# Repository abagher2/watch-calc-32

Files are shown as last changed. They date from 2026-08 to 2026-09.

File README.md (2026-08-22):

# StackCalc32 ⌚️🖩

StackCalc32 is a rebellion against slow, clunky school calculators. It completely ditches the equals sign in favor of "Stack Math" (Reverse Polish Notation)—the fastest, most efficient mental hack for solving complex math. Designed to be a world-class, rigorous tool for students, it is available as a suite of Apple ecosystem apps and as a fully open-source physical hardware device.

This monorepo contains the entire project, spanning iOS, watchOS, embedded firmware, and physical hardware designs.

## 🌟 Features

- **True Stack Math Engine**: A robust Reverse Polish Notation core (`RPNCore`) designed for precision, speed, and mathematical rigor without the mess of parentheses.
- **Cross-Platform Software**:
  - **Apple Watch App (`StackCalc32`)**: A full-featured calculator on your wrist, complete with equation plotting, statistical analysis, and complex math functions.
  - **iOS/iPadOS App (`StackCalc32-iOS`)**: A companion app featuring an immersive, haptic-enabled numpad (`HapticNumpadView`) that feels incredibly tactile—like a premium gaming device.
- **Physical Hardware**: Fully open-source 3D models and PCB designs for building your own physical StackCalc32 device. Designed to be ultra-affordable ($10-$15 retail target).
- **Embedded Firmware**: Microcontroller code powering the physical calculator.

## 🚀 The Unfair Advantage

StackCalc32 introduces several modern capabilities designed to give you a massive edge in today's high-speed engineering and math workflows:

- **RPN Equation Editor**: An intuitive editor that feels like programming, but is optimized for quick equation entry and evaluation without the overhead of full program management.
- **Equation Plotting**: Visually plot your equations directly on the screen to analyze functions, roots, and behaviors.
- **Built-in Constants**: A comprehensive library of built-in scientific constants for quick access during calculations.
- **Registers Display List**: Easily view and manage the contents of all your memory registers in a dedicated list view, rather than blindly recalling them one by one.
- **Advanced Division Operations**: Native support for division with remainders and modulus operations.
- **LFU (Least Frequently Used) Keys**: Dynamic keys that adapt to your usage, keeping the interface uncluttered while ensuring you always have access to the functions you need.

## ⌨️ Unique StackCalc32 Capabilities & Keystrokes

While the basic math and variable storage functions mirror the classic HP-32SII, StackCalc32 introduces powerful new capabilities. Here is how to use the features unique to our calculator:

### 1. RPN Equation Editor (Like Programming)
*Unlike the algebraic equation entry on the HP-32SII, StackCalc32 equations are entered as raw RPN sequences—providing the power of programming without the overhead of full program memory management.*
*Note on display formatting: The display shows the step number followed by the instruction (e.g., `3 RCL X` means step 3 is RCL X).*

*Example: Enter the equation `Y = 56 × X + 3`*

| Keystrokes | Display | Explanation |
| :--- | :--- | :--- |
| `[Blue Shift]` `[EQN]` | `EQN List` | Opens the Equation Editor list. |
| `[+]` *(New Eq)* | `LBL _` | Starts a new equation and prompts for a label. |
| `[A]` | `00 LBL A` | Assigns the equation to label A. |
| `5` `6` `[ENTER]` | `1 56` | Enters 56 into the sequence (step 1). |
| `[RCL]` `[X]` | `2 RCL X` | Recalls variable X (step 2). |
| `[×]` | `3 ×` | Multiplies 56 by X (step 3). |
| `3` `[+]` | `5 +` | Adds 3 to complete the RPN equation (steps 4 and 5). |

### 2. Equation Plotting
*Plot the equation you just entered to analyze its behavior visually.*

| Keystrokes | Display | Explanation |
| :--- | :--- | :--- |
| `[Blue Shift]` `[EQN]` | `A 56 RCL X × 3 +` | Select the equation from the list (it displays the full sequence). |
| `[Yellow Shift]` `[PLOT]` | `Plot Y(X)?` | Prompts for the independent variable to sweep (default X). |
| `[ENTER]` | `Plotting...` | Renders a high-res, pan/zoomable plot of the equation. |

### 3. Graphical Registers & Constants Lists
*Say goodbye to blindly guessing what is stored in your variables.*

| Keystrokes | Display | Explanation |
| :--- | :--- | :--- |
| `[Blue Shift]` `[REGS]` | `Registers...` | Opens a scrollable graphical list of all stored memory registers (A-Z). |
| `[Blue Shift]` `[CONST]` | `Constants...` | Opens the built-in scientific constants library for quick insertion. |

### 4. Advanced Division & Modulus
*Calculate integer division and remainders natively.*

| Keystrokes | Display | Explanation |
| :--- | :--- | :--- |
| `1` `7` `[ENTER]` `5` | `5.0000` | Pushes 17 and 5 to the stack. |
| `[Yellow Shift]` `[÷]` | `3.0000` | Integer division (`17 // 5`). |
| `[Yellow Shift]` `[MOD]` | `2.0000` | Returns the remainder (`17 % 5`). |

### 5. Dynamic LFU Keys
StackCalc32 features **Least Frequently Used (LFU)** adaptive keypads. As you use specific functions or variables, the interface gracefully adapts to surface your most-used keys, preventing you from having to dig through shift menus for your favorite operations.

## 📂 Repository Structure

To maintain a clean and organized monorepo ready for public open-source distribution, this repository strictly adheres to the following structure:

- `StackCalc32/` - The watchOS application target.
- `StackCalc32-iOS/` - The iOS/iPadOS application target (Container App).
- `RPNCore/` - The shared, core RPN mathematical engine.
- `Shared/` - Shared SwiftUI views, themes, and logic used across both Apple platforms.
- `Hardware/` - Physical calculator design files, including KiCAD schematics (`.kicad_sch`), PCB layouts (`.kicad_pcb`), OpenSCAD 3D models, and gerber files.
- `Firmware/` - Embedded Swift / C code for the physical microcontroller.
- `fastlane/` - Automated App Store screenshots, metadata, and submission scripts.
- `scratch/` - *(Git-ignored)* Directory for temporary scripts, parsed logs, exploratory testing, and raw extractions.

## 🛠️ Development & Building

### iOS & watchOS Apps

This project uses [XcodeGen](https://github.com/yonaskolb/XcodeGen) to manage the Xcode project configuration, eliminating `.pbxproj` merge conflicts.

1. Ensure XcodeGen is installed (e.g., via Homebrew): 
   ```bash
   brew install xcodegen
   ```
2. Generate the Xcode project:
   ```bash
   xcodegen generate
   ```
3. Open `StackCalc32.xcodeproj` in Xcode and select the target (`StackCalc32Container` for iOS/iPad or `StackCalc32` for Apple Watch) to build and run.

### Hardware & Firmware

- **3D Models**: Modify the `.scad` files in `Hardware/` and use the provided `generate_scad.py` script to compile the final `.stl` files for 3D printing. *(Note: To keep the repository light, `.stl` files are explicitly git-ignored).*
- **Firmware**: Built using the Apple Swift Embedded toolchain or Raspberry Pi Pico SDK. See the `Firmware/` directory for specific hardware bring-up and build instructions.

## 📄 License & Privacy

- **License**: Please refer to the [LICENSE](LICENSE) file for open-source licensing details.
- **Privacy Policy**: See the [Privacy Policy](PRIVACY_POLICY.md) for information regarding data collection (StackCalc32 does not collect or store user data).

---
*Built for the next generation of engineers who appreciate the elegance of RPN.*

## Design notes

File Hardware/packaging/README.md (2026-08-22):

# StackCalc32 Packaging & Dielines

This directory contains the physical packaging designs, dielines, and concepts for StackCalc32. Our packaging strategy employs a dual-box system tailored for both Direct-to-Consumer (D2C) e-commerce and traditional retail channels.

## 1. D2C Mailer Box
For our Amazon and D2C online sales, we use a minimalist, eco-friendly corrugated mailer.

- **Objective:** Survive shipping, reduce environmental impact, and provide a rebellious unboxing experience.
- **Design:** Kraft brown cardboard with bold, edgy black typography.
- **Slogan:** "Ditch the Equals Sign."
- **Internal:** Custom high-density foam insert cut to the exact chassis dimensions.
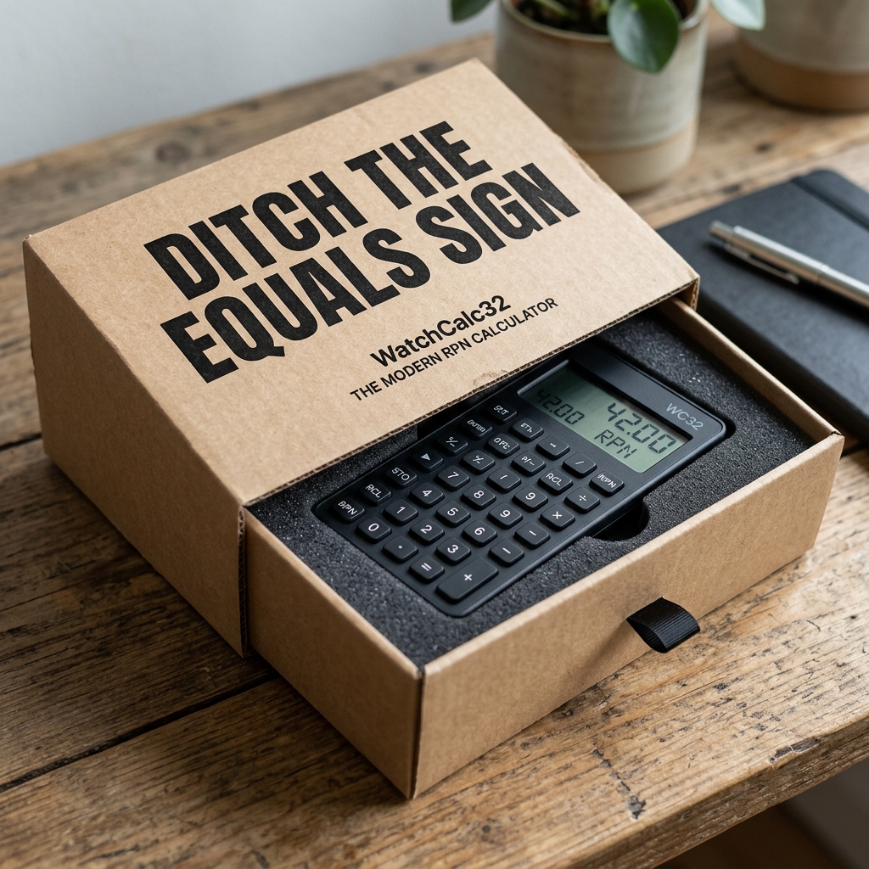
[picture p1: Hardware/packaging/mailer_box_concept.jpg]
D2C Mailer Concept
- **Concept Image:** 

## 2. Retail Display Box
For physical store shelves (e.g., Walmart, office supply stores), we use a high-gloss tuck-end box designed to pop off the shelf and appeal to students/teenagers.

- **Objective:** Maximum shelf appeal, highlight the modern UI, and clearly differentiate from boring legacy calculators.
- **Design:** Dark mode aesthetics with vibrant neon/tech accents. Features high-res screenshots of the equation editor and plot view.
- **Interactive:** Large QR code on the front linking directly to the companion app/tutorials.
- **Slogan:** "Ditch the Equals Sign."
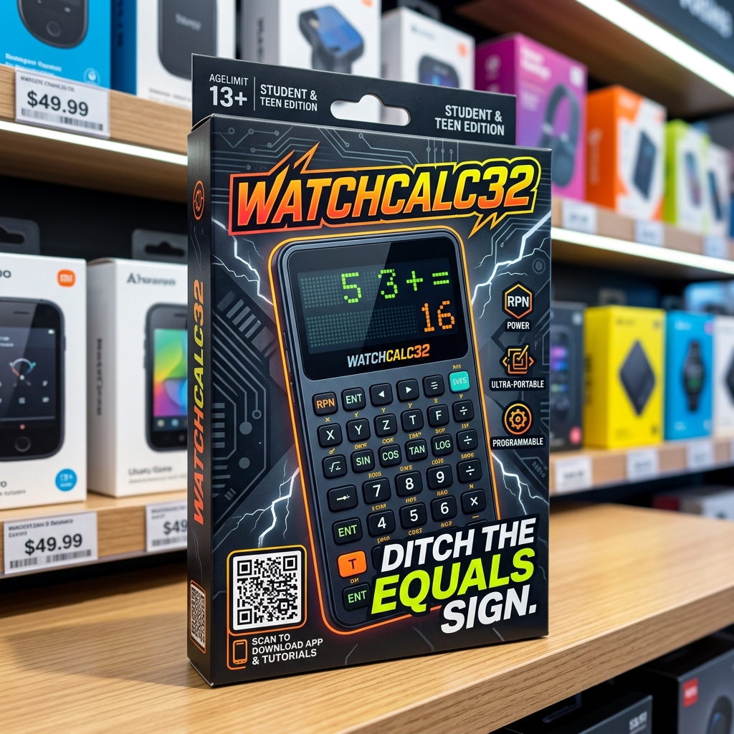
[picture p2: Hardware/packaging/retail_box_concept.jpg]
Retail Box Concept
- **Concept Image:** 

## 3. Production Specs & Cost of Goods Sold (COGS)
To achieve our target retail price of **$10–$15**, the total manufacturing cost (COGS) must remain strictly under **$4.00 per unit** to allow for 3PL, freight, and retail margins.

### BOM Target Breakdown ($3.50 total):
- **MCU:** CH32V or RP2040 (~$0.15 - $0.70)
- **Display:** 1.8" Monochrome Graphic LCD SPI (~$0.85)
- **Keypad:** Silicone dome membrane keypad with printed plastic caps (~$0.40)
- **Chassis:** Injection-molded ABS plastic (~$0.50)
- **Packaging:** 300gsm tuck-end box with molded pulp tray (more sustainable and cheaper than EVA foam) (~$0.30)
- **PCBA & Assembly Labor:** (~$0.60)

*Note: We cannot use premium mechanical keyboard switches or full-color OLED screens without breaking this strict budget constraint.*

## Next Steps for Production
1. **Dieline Generation:** Once the final chassis dimensions are locked in `Hardware/designs/chassis.scad`, we will generate 2D `.dxf` / `.ai` dielines for the box fold patterns based on the 300gsm tuck-end spec.
2. **Pulp Tray Routing:** Generate step files for the internal molded pulp tray so the manufacturer can press the exact cutout for the calculator and charging cable.
3. **Artwork Layout:** Apply the high-res marketing renders to the flattened dielines for printing.

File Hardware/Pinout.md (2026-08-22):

# RP2040-Zero PCB Pinout & Wiring Plan

To test the connections on your custom PCB, map out exactly which GPIO pins connect to which components.

## 1. Pin Assignments (Modern Layout)

This pinout maps to the 43-key Modern matrix (8 rows x 6 columns) as generated by our KiCad config.

### OLED Display (I2C)
*   **VCC** -> 3.3V (Out)
*   **GND** -> GND
*   **SDA** -> GP0
*   **SCL** -> GP1

### Keyboard Matrix (6 Columns x 8 Rows)
The RP2040 will pull the 6 columns low sequentially and read the 8 rows to scan all 43 physical keys.

**Column Pins (Outputs):**
*   **Col 1** -> GP10
*   **Col 2** -> GP11
*   **Col 3** -> GP12
*   **Col 4** -> GP13
*   **Col 5** -> GP14
*   **Col 6** -> GP15

**Row Pins (Inputs with Pull-ups):**
*   **Row 1 (Top)** -> GP5
*   **Row 2** -> GP6
*   **Row 3** -> GP7
*   **Row 4** -> GP8
*   **Row 5** -> GP26
*   **Row 6** -> GP27
*   **Row 7** -> GP28
*   **Row 8 (Bottom)** -> GP29

---

## 2. Testing the Board
Once your PCB is manufactured and soldered, plug the RP2040-Zero into your computer via USB-C. 
Install **MicroPython** on it, and run the `board_test.py` script provided in this folder to verify all 43 keys register correctly.

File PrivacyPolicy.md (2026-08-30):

# Privacy Policy

**Effective Date:** 2024-05-15

StackCalc32 ("the App") is designed with your privacy in mind. This policy explains our data practices.

## 1. Data Collection
StackCalc32 operates entirely locally on your device (iPhone, iPad, or Apple Watch). 
We do not collect, transmit, store, or share any personal information, usage data, or calculations.

All calculator states, memory registers, user equations, and settings are stored locally on your device using standard Apple frameworks (such as UserDefaults) and are never shared.

### Third-Party Services
The App does not integrate with any third-party analytics or advertising services. 

### Contact Us
If you have any questions regarding this privacy policy or our data practices, please open an issue on our GitHub repository.

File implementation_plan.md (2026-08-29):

# Fix Spring Attachments, ENTER Shaft, and Key Labels

This plan addresses all issues found in the recent slicer review of the print-in-place calculator keypad.

## Proposed Changes

### 1. Fix Spiral Spring Attachments
- **Issue:** The spiral springs currently stop at `r=4.0`, while the button cavity is `w+btn_gap` (~9.3mm). This leaves the ends of the springs floating in mid-air, requiring supports.
- **Fix:** Modify `button_solid` to calculate the exact distance to the cavity wall (`w/2 + btn_gap/2`). Extend the `spiral_arm` radius to completely bridge the gap.
- **Result:** The spiral arms will fuse perfectly to the faceplate cavity walls during slicing, anchoring the buttons without any supports.

### 2. Fix ENTER Button Shaft
- **Issue:** The ENTER button was generated with two inner shafts, which does not align with the single tactile switch on the PCB.
- **Fix:** Remove the `if (w > 15)` double-shaft logic in `generate_scad.py`. All buttons (including ENTER) will use a single, centrally-aligned inner shaft and spring mechanism.

### 3. Extract and Apply All iOS App Labels
- **Issue:** Side labels were only applied to a few keys using dummy data.
- **Fix:** Parse `HP32KeyMap.swift` to extract the `yellowLabel`, `blueLabel`, and `alphaLabel` for every single key on the grid.
- **Mapping:** 
  - `yellowLabel` -> Left Skirt (`label_left`)
  - `blueLabel` -> Right Skirt (`label_right`)
  - `alphaLabel` -> Front Skirt (`label_alpha`)

### 4. Rotate and Deepen Side Labels
- **Issue:** Side labels are oriented vertically, and the emboss depth is too shallow.
- **Fix:** Update the label `rotate()` transformations in `generate_scad.py` so they read horizontally (left-to-right) along the Y-axis. Increase the subtraction depth to `0.8mm` to ensure they slice clearly.

## User Review Required
Please approve this plan so I can proceed with patching the Python generator and extracting the exact labels from your iOS source code!

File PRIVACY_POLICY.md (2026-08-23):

# Privacy Policy

**Effective Date:** August 19, 2026

StackCalc32 ("the App") is an RPN scientific calculator application provided for iOS, iPadOS, and watchOS devices.

## Data Collection and Use
We do not collect, store, transmit, or share any personal information, usage data, or analytics from your device. All calculations and operations performed within the App occur locally on your device.

## Third-Party Services
The App does not use any third-party services that may collect information used to identify you.

## Changes to This Privacy Policy
We may update our Privacy Policy from time to time. Thus, you are advised to review this page periodically for any changes. We will notify you of any changes by posting the new Privacy Policy on this page. These changes are effective immediately after they are posted on this page.

## Contact Us
If you have any questions or suggestions about our Privacy Policy, do not hesitate to contact us by creating an issue in this repository.

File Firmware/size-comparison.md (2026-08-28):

## SwissMicros DM32 (Modern Clone):
Width: 77.0 mm
Height: 144.0 mm
Depth: 12.0 mm

## Original HP-32SII (Authentic Vintage):
Width: 85.0 mm
Height: 148.0 mm
Depth: 15.0 mm

## Our StackCalc 32 (Bare Chassis):
Width: 76.0 mm
Height: 148.0 mm
Depth: ~15.0 mm

## Our StackCalc 32 (with TPU Cover):
Width: 79.2 mm
Height: 151.2 mm
Depth: ~16.6 mm

**StackCalc 32 Screen**
https://www.buydisplay.com/2-5-inch-132x65-arduino-lcd-display-module-serial-spi-black-on-white

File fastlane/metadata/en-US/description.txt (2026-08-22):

Ditch the equals sign. WatchCalc 32 is a rebellion against slow, boring, clunky school calculators. 

Tired of getting lost in a mess of parentheses on your math homework? WatchCalc 32 uses "Stack Math" (Reverse Polish Notation)—the fastest, most efficient mental hack for solving complex math. It's like a cheat code for your exams. Built as a companion app to the physical WatchCalc 32 hardware, this app gives you pure mathematical power across your iPhone, iPad, and Apple Watch.

### Key Features

• Stack Math (RPN) Logic: Experience raw speed. Type your numbers, stack them up, and execute. No equals sign required.
• Purpose-Built for Exams: Intentionally non-programmable so you can actually use it in class without getting flagged by your teacher.
• Powerful Engine: Tackle advanced operations including exact fractions, complex numbers, statistics, trigonometry, and base conversions.
• Equation Plotting: Evaluate and visualize complex equations instantly with dynamic, full-screen interactive graphs. 
• True Cross-Platform: Fully optimized. Hyper-efficient layout on Apple Watch, one-handed portrait mode on iPhone, and an expansive landscape mode on iPad.
• Edgy Aesthetics: Dark mode, neon accents, and tactile haptic feedback that makes it feel like you're holding a premium gaming device, not a 1990s school supply.

Download the ultimate mathematical cheat code and never press equals again.

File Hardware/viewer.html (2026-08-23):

# WatchCalc 32 Assembly

Loading models...

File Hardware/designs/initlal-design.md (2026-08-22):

StackCalc32: Apple Watch RPN CalculatorVersion: 1.0 (Architecture & UI Specification)Target Platform: watchOS 10+ (Apple Watch Series 7, 8, 9, Ultra)Frameworks: SwiftUI, Charts, Swift 5.9, C/C++Core Engine: Advanced (WP43S) or Free42 C/C++ Core1. Executive SummaryStackCalc32 brings the mathematical rigor of the HP-32SII and Advanced to the Apple Watch. It solves the "micro-button" problem of watch calculators by utilizing a Continuous Vertical Ribbon (a scrolling UI), Screen-Wide Gestures (eliminating modifier keys), and Native Apple Input (for variables and equations). The aesthetic mimics the molded plastic of the Pioneer chassis (e.g., SwissMicros Modern).2. System ArchitectureThe application strictly decouples the UI from the math engine using a Local Swift Package Manager (SPM) architecture.2.1 Workspace StructureWatchCalcWorkspace/
├── StackCalc32_AppTarget/
│   ├── UI Components (SwiftUI)
│   └── App.swift
└── RPNCore (Local Swift Package)/
    ├── Package.swift
    ├── Sources/
    │   ├── CEngine/
    │   │   ├── include/CEngine.h (C Public API)
    │   │   └── core_logic.c (Advanced/Free42 source)
    │   └── RPNCore/
    │       └── CalculatorEngine.swift (Swift Wrapper)
2.2 The State Machine (CalculatorEngine.swift)The Swift layer acts as a bidirectional terminal between SwiftUI and the C core.import Foundation
import CEngine
import SwiftUI

@Observable
public class CalculatorEngine {
    // Standard Display State
    public var displayX: String = "0.0000"
    public var promptString: String? = nil // Handles display takeovers e.g. "STO _"
    
    // Shift State: 0=None, 1=Yellow(f), 2=Blue(g)
    public var shiftState: Int = 0 
    
    // 8-Level Stack Array (For Overlay)
    public var stack: [String] = Array(repeating: "0.0000", count: 8)
    
    // Mode Tracking
    public var isEquationMode: Bool = false
    public var equationString: String = ""
    
    public init() {
        c47_init()
        updateState()
    }
    
    public func execute(command: String) {
        // Map string identifier to C command and execute
        c47_execute_cmd(mapToID(command))
        updateState()
    }
    
    public func setShift(_ state: Int) {
        self.shiftState = state
        WKInterfaceDevice.current().play(.click)
    }
    
    private func updateState() {
        // Pseudo-logic to query C Engine
        if c47_is_waiting_for_input() {
            self.promptString = String(cString: c47_get_prompt())
        } else {
            self.promptString = nil
            self.displayX = String(cString: c47_get_display_x())
        }
        
        // Update deep stack
        for i in 0..<8 {
            if let val = c47_get_stack_level(Int32(i)) {
                self.stack[i] = String(cString: val)
            }
        }
    }
}
3. The Universal Gesture MatrixButtons on the screen act as static spatial targets. All modifiers and actions are routed through watchOS screen gestures.GestureActionEngine CommandHaptic FeedbackSwipe UpPush to StackENTER.successSwipe DownClear X / Cancel MenuCLx / EXIT.retrySwipe LeftReveal Math Operators PadN/A (UI state).directionUpSwipe RightReveal ASSIGN (LFU) MenuN/A (UI state).directionDownSwipe Display LeftToggle Yellow Shift (f)N/A (UI state).clickSwipe Display RightToggle Blue Shift (g)N/A (UI state).click (Double)Tap DisplayOpen 8-Level Stack OverlayN/A (UI state).clickDigital CrownScroll Keyboard RibbonN/A (UI state)Native Detents4. Visual Language & AestheticsThe UI simulates molded plastic with inner highlights and drop shadows, avoiding bitmaps for Retina sharpness.4.1 Color Paletteextension Color {
    static let dmChassis = Color(white: 0.1) // Background
    static let dmDigitKey = Color(white: 0.85) // 0-9
    static let dmFunctionKey = Color(white: 0.25) // Math functions
    static let dmYellowShift = Color(red: 1.0, green: 0.8, blue: 0.1)
    static let dmBlueShift = Color(red: 0.2, green: 0.8, blue: 1.0)
}
4.2 The Pioneer Button Stylestruct PioneerButtonStyle: ButtonStyle {
    var isDigit: Bool
    
    func makeBody(configuration: Configuration) -> some View {
        configuration.label
            .background(
                RoundedRectangle(cornerRadius: 6, style: .continuous)
                    .fill(isDigit ? Color.dmDigitKey : Color.dmFunctionKey)
            )
            .overlay( // 3D Top Bevel
                RoundedRectangle(cornerRadius: 6, style: .continuous)
                    .stroke(LinearGradient(gradient: Gradient(colors: [.white.opacity(0.4), .clear]), startPoint: .topLeading, endPoint: .bottomTrailing), lineWidth: 1.5)
            )
            .shadow(color: .black.opacity(configuration.isPressed ? 0.0 : 0.6), radius: configuration.isPressed ? 0 : 2, y: configuration.isPressed ? 0 : 2)
            .scaleEffect(configuration.isPressed ? 0.92 : 1.0)
    }
}
5. Viewport / Layout SpecificationsThe UI exists in a single vertical ScrollView. As the user scrolls up via the Crown, the grid safely expands from 3 columns to 4.5.1 The LCD Display (Pinned Header)A static, single-line display pinned to the top of the screen. Utilizes SF Mono Bold. If promptString is active, it takes over the X-register view.5.2 The Bottom Viewport (Data Entry - 3x4 Grid)Scroll Offset = 0.7, 8, 94, 5, 61, 2, 30, ., +/-5.3 The Upper Matrix (Scientific - 4x5 Grid)Scroll Offset < 0. Located directly above the Numpad.STO, RCL, x><y, R↓1/x, √x, LN, LOGSIN, COS, TAN, R/SFN=, ∫, ABS, INTGLBL, GTO, EQN, SOLVE5.4 The "Hold to Preview" LogicTo prevent accidental shifted clicks, custom gesture logic replaces standard buttons in the Upper Matrix:Touch Down: Shows the key's target function (e.g., "ASIN") on the LCD promptString.Drag Away: Cancels the press and clears the LCD preview.Release inside bounds: Executes the function.6. Advanced Subsystems6.1 Native Alpha Entry (Variables / STO)When the Advanced engine waits for a variable (e.g., STO _), the UI must trigger the native watchOS text entry.engine.promptString updates to "STO _".SwiftUI triggers .sheet(isPresented: $isWaitingForAlpha).User utilizes Apple Scribble or QWERTY keyboard.OnSubmit, Swift sanitizes to a single uppercased String and passes CMD_ALPHA_A to Advanced.6.2 Equation & Solve EngineWhen EQN is active, the single-line LCD swaps to a horizontal ScrollView (Ticker).Users can type equations via the 4x5 ribbon OR tap a keyboard icon to open native watchOS dictation/keyboard.Swift parses Y=3X^2 string into sequential Advanced engine commands.6.3 Plotting / Graphing Engine (Oscilloscope Mode)Integrated via SwiftUI Charts. Triggered from Equation mode.struct FullScreenPlotView: View {
    @StateObject var plotEngine: PlotEngine // Runs loop to evaluate Advanced equation 150 times
    @State private var crownZoom: Double = 10.0
    
    var body: some View {
        Chart(plotEngine.dataPoints) { point in
            LineMark(x: .value("X", point.x), y: .value("Y", point.y))
                .interpolationMethod(.monotone)
                .foregroundStyle(Color.dmBlueShift)
        }
        .chartXScale(domain: -crownZoom...crownZoom)
        .chartYScale(domain: -crownZoom...crownZoom)
        .focusable(true)
        .digitalCrownRotation($crownZoom, from: 1, through: 100, sensitivity: .medium)
    }
}
7. Recommended Development PhasesPhase 1: SPM & Engine. Create local package, wrap Advanced/Free42 C code, build bidirectional @Observable engine class.Phase 2: Skin & Gestures. Build the Modern UI components, the 3x4 Numpad, and wire the Swipe Up/Down/Left gestures.Phase 3: The Ribbon. Implement the ScrollView, the 4x5 upper matrix, and the display header logic (shift states).Phase 4: Integrations. Add the Native watchOS text field handoffs for Alpha entry and the SwiftUI Charts for plotting.

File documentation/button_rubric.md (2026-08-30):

# HP32SII Deviation Rubric

This document tracks **only the ways StackCalc32 intentionally deviates from the original HP32SII**. Any key combination not listed here is expected to behave identically to the HP32SII (or DM32 where noted). Refer to the [HP 32SII Owner's Manual](https://www.hpcalc.org/hp32s/) and [DM32 User Manual](https://technical.swissmicros.com/dm32/) for baseline behavior.

For a full description of how every menu operates across all surfaces, see [menu_operation.md](menu_operation.md).

---

## Base State — Key Remaps & Additions

These keys exist on the physical StackCalc32 hardware but **differ in label or function** from the HP32SII.

| Button / Combo | HP32SII Original | StackCalc32 | Rationale |
|---|---|---|---|
| **BLUE + +/-** | `(` (open parenthesis — for EQN/solver entry) | `\|x\|` (Absolute Value) | Parentheses are less useful in RPN direct mode; ABS is more ergonomic. |
| **BLUE + E** | `)` (close parenthesis — for EQN/solver entry) | `÷R` (Integer Division) | Parentheses serve EQN mode only; `÷R` is more useful as a direct key. |
| **BLUE + <-** | `=` (equals — for EQN/solver entry) | *(no function)* | `=` is not needed in RPN mode; key is left unassigned. |
| **YELLOW + 0** | `INPUT` (program input prompt — recall var and show name+value) | `REGS` (Show Registers) | `INPUT` is programming-only. StackCalc32 repurposes the key for the register viewer. |
| **PLOT** | *(key does not exist on HP32SII)* | Opens Plot Mode | StackCalc32-exclusive key. Not on the HP32SII or DM32. |
| **YELLOW + PLOT** | *(key does not exist)* | `CNST` (Physical Constants Menu) | StackCalc32-exclusive. HP32SII has no built-in constants menu; users stored constants in registers. |

---

## LFU Row (Top 6 Dynamic Softkeys)

The **LFU (Least Frequently Used) row** is a StackCalc32-exclusive feature. The HP32SII has **no dedicated softkey row** — its top row of keys (`√𝑥`, `𝑒ˣ`, `LN`, `𝑦ˣ`, `¹/𝑥`, `Σ+`) are always fixed math function keys, with no dynamic softkey strip at all.

StackCalc32 permanently reserves the top 6 keys as a dynamic, context-aware softkey strip. In menu contexts, this LFU row repurposes identically to how the HP32SII repurposed its numeric top row — except it is reserved for this purpose at all times rather than only during menus.

| Context | HP32SII Original | StackCalc32 Firmware / RetroUI | iOS / watchOS |
|---|---|---|---|
| **Normal State** | Top row = `√𝑥 𝑒ˣ LN 𝑦ˣ ¹/𝑥 Σ+` (always fixed) | Top row shows 6 most recently used functions (LFU algorithm) | N/A — no physical row |
| **Menu Active** | Top numeric row remapped to softkey labels | LFU row remaps to softkeys (e.g., `FIX SCI ENG ALL`) | Native sheet / list replaces entirely |
| **EQN List** | *(no softkeys — navigate with `↓`/`↑` only)* | LFU row shows `EQN_NEW`, `EQN_EDIT` softkeys | Native list with `+` button and swipe-to-delete |

---

## Menu Navigation Model

All menus exist on all three surfaces and produce identical calculator results. The **mechanism** differs by surface. This is not a functional deviation — it is a platform adaptation.

| Surface | How Menus Are Navigated |
|---|---|
| **HP32SII** | Physical softkey row (top numeric keys) remapped to menu labels during menu state. User presses the key physically below the label on the LCD. Multi-page menus use a `▸` page key. |
| **Firmware / RetroUI** | LFU row replaces the softkey row. Same single-press selection. `requiresDigit` menus (FIX, SCI, ENG, SF, CF) wait for a follow-up digit keypress on the same row. |
| **iOS** | Native modal sheet with tappable list items. `requiresDigit` menus present an inline digit picker. Dismisses automatically after selection. |
| **watchOS** | Full-screen SwiftUI list. Tap or Digital Crown to select. Sub-picker for digit-requiring options. |

> [!NOTE]
> See [menu_operation.md](menu_operation.md) for the complete per-menu breakdown of items and behavior on each surface.

The following menus are present on all surfaces with **no functional deviation** from the HP32SII. Only the navigation mechanism differs as described above:

| Menu | Trigger | HP32SII Items | StackCalc32 Additions |
|---|---|---|---|
| **DISP** | `YELLOW + E` | `FIX n`, `SCI n`, `ENG n`, `ALL` | — |
| **MODES** | `YELLOW + +/-` | `DEG`, `RAD`, `GRAD` | — |
| **BASE** | `YELLOW + ×` | `HEX`, `DEC`, `OCT`, `BIN` | — |
| **CLEAR** | `YELLOW + <-` | `CLx`, `CLVARS`, `CLΣ`, `ALL` *(PGM only in PRGM mode)* | `CLEQN`, `CLREGS`, `CLSTK` added as always-visible items |
| **FLAGS** | `BLUE + ×` | `SF n`, `CF n`, `FS? n`, `FC? n` | `4-LVL`, `8-LVL`, `INF` stack-size options |
| **MEM** | `YELLOW + x≷y` | `VARS`, `PRGM`, `REGS` | — |
| **PARTS** | `BLUE + √𝑥` | `IP`, `FP`, `ABS` | `SGN` added |
| **PROB** | `BLUE + 𝑒ˣ` | `Cn,r`, `Pn,r`, `𝑥!`, `RAND` | — |
| **SUMS** | `BLUE + Σ+` | `Σx`, `Σy`, `Σx²`, `Σy²`, `Σxy`, `n` | — |
| **𝑥̄,𝑦̄** | `BLUE + 𝑦ˣ` | `x̄`, `ȳ`, `x̄w` | — |
| **s,σ** | `BLUE + ¹/𝑥` | `sx`, `sy`, `σx`, `σy` | — |
| **L.R.** | `BLUE + LN` | `ŷ`, `x̂`, `r`, `m`, `b` | — |
| **𝑥?𝑦** | `YELLOW + ÷` | `x=y`, `x≠y`, `x>y`, `x<y`, `x≥y`, `x≤y` | — |
| **𝑥?0** | `BLUE + ÷` | `x=0`, `x≠0`, `x>0`, `x<0`, `x≥0`, `x≤0` | — |

---

## Modeless / State-Specific Deviations

### 1. Programming / Equation Mode (EQN Edit)

> [!IMPORTANT]
> This is the **largest intentional deviation** from the HP32SII.

The HP32SII uses **algebraic entry** for equations (e.g., `SIN(X) + 1`). StackCalc32 intentionally deviates: all equation equations use **RPN instruction entry** (appending steps like `SIN`, `1`, `+`). This creates a unified execution model across the physical device, iOS, and watchOS.

| Button / Combo | HP32SII Original | StackCalc32 |
|---|---|---|
| **Base Functions (SIN, COS, etc.)** | Appends algebraic text character(s) to equation | Appends RPN instruction step |
| **Numpad** | Appends digit(s) to algebraic expression | Appends numeric constant as a discrete step |
| **ENTER** | Submits the algebraic equation | Commits the current RPN program to storage |
| **`<-` / C** | Backspaces one character in algebraic string | Deletes the previous RPN instruction step |

---

### 2. Plot Mode — `PLOT` key

The HP32SII has **no Plot Mode**. This entire section is a StackCalc32 extension.

| Button / Combo | HP32SII Original | StackCalc32 |
|---|---|---|
| **PLOT** | *(key does not exist)* | Enters Plot Mode — transitions UI to graph renderer |
| **Numpad 2/4/6/8** | *(N/A)* | Pans graph (Down/Left/Right/Up) |
| **+ / -** | *(N/A)* | Zooms in/out |
| **`<-` / C** | *(N/A)* | Exits plot, returns to normal mode |
| **LFU Keys (Top 6)** | *(N/A)* | Reserved for trace mode (not yet implemented) |

---

### 3. Alpha Mode — Platform Differences Only

The Alpha entry mode (triggered by `STO _`, `RCL _`, `XEQ _`, etc.) behaves identically to the HP32SII on the Firmware/RetroUI surface. The iOS and watchOS surfaces deviate only at the **input mechanism level** — the calculator engine behavior is identical.

| Platform | Alpha Input Method | Deviation from HP32SII? |
|---|---|---|
| **Firmware / RetroUI** | Physical alpha key labels (`A`–`Z` printed on key faces) | **No deviation** |
| **iOS** | Native iOS keyboard sheet | UI-level only — engine accepts same inputs |
| **watchOS** | Full-screen A–Z picker | UI-level only — engine accepts same inputs |

---

### 4. Error Handling and Prompts (Nuanced Deviations)

*   **Error States**: When an operation causes a mathematical exception (e.g., `DIVIDE BY 0`, `INVALID DATA`, `OVERFLOW`, `STAT ERROR`), the engine halts and displays the error message on the LCD.
    *   **Deviation from HP32SII**: On the original hardware, pressing a key while an error is displayed both clears the error *and* immediately executes the key's function. In StackCalc32, any keypress while an error is displayed is **swallowed entirely**. The first keypress strictly clears the error state and resets the UI, requiring the user to press the key a second time to execute it.
*   **Prompt Aborts**: When the engine is waiting for a specific digit (e.g., `FIX _` or `SF _`), pressing a random mathematical key (like `+` or `SIN`) is **swallowed entirely**, and the calculator **remains in the prompt state**. The only way to abort the prompt is to explicitly press `C` or `<-`.
*   **Menu Input**: In the Firmware/RetroUI, menus intercept keystrokes. If a key has an `alphaLabel` (like `J` for the `SIN` key), it will filter the menu items alphabetically rather than executing the math function.

---
## Summary: StackCalc32-Only Additions (Not on HP32SII)

| Feature | Key / Trigger | HP32SII Original | Notes |
|---|---|---|---|
| LFU Dynamic Softkey Row | Top 6 physical keys | Fixed math keys (`√𝑥 𝑒ˣ LN 𝑦ˣ ¹/𝑥 Σ+`) | HP32SII had no softkey row |
| Physical Constants Menu (`CNST`) | `YELLOW + PLOT` | *(key doesn't exist)* | HP32SII: users stored constants in registers |
| Plot Mode | `PLOT` (dedicated key) | *(key doesn't exist)* | Full graphing; HP32SII had no plot capability |
| Register Viewer (`REGS`) | `YELLOW + 0` | `INPUT` (program input prompt) | Repurposes a programming-only key |
| Absolute Value (`\|x\|`) | `BLUE + +/-` | `(` (open parenthesis for EQN) | Parentheses less useful in RPN direct mode |
| Integer Division (`÷R`) | `BLUE + E` | `)` (close parenthesis for EQN) | Parentheses less useful in RPN direct mode |
| `CLEQN`, `CLREGS`, `CLSTK` | Inside `CLEAR` menu | Not in HP32SII CLEAR menu | HP32SII CLEAR has: `CLx`, `CLVARS`, `CLΣ`, `ALL` |
| `SGN` | Inside `PARTS` menu | Not in HP32SII PARTS menu | HP32SII PARTS has: `IP`, `FP`, `ABS` |
| Stack Size Flags (`4-LVL`, `8-LVL`, `INF`) | Inside `FLAGS` menu | HP32SII has a fixed 4-level stack | |
| `EQN_NEW`, `EQN_EDIT` softkeys | LFU row in EQN List | *(no softkeys in EQN list)* | HP32SII navigates equations with `↓`/`↑` only |
| `km ↔ mi` Conversions | `YELLOW + 9`, `BLUE + 9` | *(not present)* | StackCalc32 adds km/mi conversions (`->km`, `->mi`) |
| Modulo (`MOD`) | Engine-level | *(not present)* | Supported natively, though not currently mapped to a default physical key |

---

## Summary: Omitted HP32SII Features

The following features from the original manuals have been intentionally omitted or completely replaced by StackCalc32 design choices:

| Omitted Feature | HP32SII Key / Trigger | Rationale for Omission |
|---|---|---|
| **Run/Stop (`R/S`)** | `R/S` physical key | Replaced entirely by the **`PLOT`** key. |
| **Program Mode (`PRGM`)** | `YELLOW + R/S` | Replaced by `CNST` (Physical Constants). Programming mode omitted. |
| **Pause (`PSE`)** | `BLUE + R/S` | Omitted along with the `R/S` key. |
| **Go To (`GTO`)** | Branching Instruction | Omitted. Traditional programming branching is not supported. |
| **Algebraic Equation Entry** | `=`, `(`, `)` | Replaced by RPN step entry. Keys were repurposed to `\|x\|`, `÷R`, and unassigned. |

## Appendix: Shared Operations & Fuzzer Seeds

This section details the operations that are **identical** between the original HP32SII (and DM32) and StackCalc32. These common operations serve as the foundation for the calculator engine. The examples provided here are intended to be used as **seeds for fuzzer testing** to ensure parity across all platforms (Hardware, iOS, watchOS).

### 1. Menu-Driven Operations

Menus require a sequence of keystrokes. The fuzzer must be able to navigate the menu and provide any required follow-up arguments (like a digit for `FIX`).

#### Display Formatting (`DISP` Menu)
Controls how numbers are rendered on the LCD.
*   **`FIX`**: Fixed decimal places. Requires a digit (0-9). Example: `[YELLOW] [DISP] [FIX] [4]` (Sets 4 decimal places).
*   **`SCI`**: Scientific notation. Requires a digit (0-9). Example: `[YELLOW] [DISP] [SCI] [2]` (Sets scientific with 2 decimal places).
*   **`ENG`**: Engineering notation. Requires a digit (0-9). Example: `[YELLOW] [DISP] [ENG] [3]`.
*   **`ALL`**: Show all significant digits. Example: `[YELLOW] [DISP] [ALL]`.

#### Angular Modes (`MODES` Menu)
Controls trigonometric interpretation.
*   **`DEG`**: Degrees. Example: `[YELLOW] [MODES] [DEG]`.
*   **`RAD`**: Radians. Example: `[YELLOW] [MODES] [RAD]`.
*   **`GRAD`**: Gradians. Example: `[YELLOW] [MODES] [GRAD]`.

#### Base & Logic Modes (`BASE` Menu)
Changes the integer base and enables bitwise operations.
*   **`HEX`**, **`DEC`**, **`OCT`**, **`BIN`**. Example: `[YELLOW] [BASE] [HEX]`.
*   **Logic Operations**: `AND`, `OR`, `XOR`, `NOT`. Example in HEX mode: `[A] [ENTER] [5] [BLUE] [AND]` (Result: 0).

#### Number Parts (`PARTS` Menu)
Extracts components of a number.
*   **`IP`**: Integer part. Example: `[1] [.] [5] [BLUE] [PARTS] [IP]` (Result: 1).
*   **`FP`**: Fractional part. Example: `[1] [.] [5] [BLUE] [PARTS] [FP]` (Result: 0.5).
*   **`ABS`**: Absolute value. (Also mapped to `BLUE + +/-`). Example: `[-] [5] [BLUE] [PARTS] [ABS]` (Result: 5).

#### Probability (`PROB` Menu)
*   **`nCr` (Combinations)**: Items in Y, choose X. Example: `[5] [ENTER] [2] [BLUE] [PROB] [nCr]` (Result: 10).
*   **`nPr` (Permutations)**: Items in Y, arrange X. Example: `[5] [ENTER] [2] [BLUE] [PROB] [nPr]` (Result: 20).
*   **`𝑥!` (Factorial)**: Example: `[5] [BLUE] [PROB] [𝑥!]` (Result: 120).
*   **`RAND`**: Generates a pseudo-random number $0 \le x < 1$. Example: `[BLUE] [PROB] [RAND]`.

#### Flags (`FLAGS` Menu)
Sets and clears boolean system flags. Requires a digit (0-9).
*   **`SF` (Set Flag)**: Example: `[BLUE] [FLAGS] [SF] [1]`.
*   **`CF` (Clear Flag)**: Example: `[BLUE] [FLAGS] [CF] [1]`.
*   **`FS?` / `FC?`**: Tests if flag is set/clear (useful in equations).

---

### 2. Standard Mathematical Operations

#### Basic Arithmetic & Unary
*   `+`, `-`, `×`, `÷`: Standard binary operators.
*   `√𝑥`: Square root. Example: `[9] [√𝑥]` (Result: 3).
*   `𝑥²`: Square. Example: `[3] [YELLOW] [𝑥²]` (Result: 9).
*   `𝑦ˣ`: Power. Example: `[2] [ENTER] [3] [𝑦ˣ]` (Result: 8).
*   `¹/𝑥`: Reciprocal. Example: `[4] [¹/𝑥]` (Result: 0.25).
*   `𝑒ˣ`, `LN`, `10ˣ`, `LOG`: Exponential and logarithmic functions.

#### Trigonometry
*   `SIN`, `COS`, `TAN`: Standard trig.
*   `ASIN`, `ACOS`, `ATAN`: Inverse trig (Yellow shifted).
*   **Fuzzer Seed**: `[3] [0] [SIN]` (In DEG mode, Result: 0.5).

#### Percentages
*   `%`: Calculates X percent of Y. Example: `[1] [0] [0] [ENTER] [5] [%]` (Result: 5).
*   `%CHG`: Percent change from Y to X. Example: `[1] [0] [0] [ENTER] [1] [1] [0] [BLUE] [%CHG]` (Result: 10).

---

### 3. Stack Manipulation

*   **`ENTER`**: Duplicates X to Y and disables stack lift.
*   **`x≷y`**: Swaps X and Y registers. Example: `[1] [ENTER] [2] [x≷y]` (X becomes 1, Y becomes 2).
*   **`R↓` (Roll Down)**: Rotates stack downward.
*   **`R↑` (Roll Up)**: Rotates stack upward (Blue shifted).
*   **`LAST𝑥`**: Recalls the value of X prior to the last operation. Example: `[5] [ENTER] [3] [+] [YELLOW] [LAST𝑥]` (X becomes 3).

---

### 4. Memory and Variables

*   **`STO` (Store)**: Requires an alpha character. Example: `[5] [STO] [A]`.
*   **`RCL` (Recall)**: Requires an alpha character. Example: `[RCL] [A]` (Result: 5).
*   **Storage Arithmetic**: Performs math directly on variables. Example: `[1] [0] [STO] [+] [A]` (Adds 10 to variable A).

---

### 5. Statistics & Sums

Statistics require accumulating data points into the summing registers.
*   **`Σ+`**: Adds the X (and Y) values to the statistical registers. Example: `[5] [ENTER] [2] [Σ+]`.
*   **`Σ-`**: Removes a data point.
*   **`SUMS` Menu**: Accesses the raw accumulation registers (`Σx`, `Σy`, `Σx²`, `Σy²`, `Σxy`, `n`).
*   **`𝑥̄,𝑦̄` Menu**: Means (`x̄`, `ȳ`, `x̄w`).
*   **`s,σ` Menu**: Sample and population standard deviations (`sx`, `sy`, `σx`, `σy`).
*   **`L.R.` Menu**: Linear regression (`ŷ`, `x̂`, `r`, `m`, `b`).

---

### 6. Logical Tests

Tests the X and Y registers. If the test is true in normal mode, nothing happens (execution proceeds). If false, it acts as a visual test or skips a step in equations.
*   **`x?y` Menu**: `x=y`, `x≠y`, `x>y`, `x<y`, `x≥y`, `x≤y`. Example: `[YELLOW] [x?y] [x=y]`.
*   **`x?0` Menu**: `x=0`, `x≠0`, `x>0`, `x<0`, `x≥0`, `x≤0`. Example: `[BLUE] [x?0] [x=0]`.

### 7. Nuanced Behaviors & Edge Cases (Fuzzer Targets)

To ensure the Fuzzer deeply validates parity, here are the more esoteric features that are accurately ported from the original hardware:

#### Fractions & Denominator Control (`/c` and `FDISP`)
*   **Toggle Fraction Mode**: `[.] [YELLOW] [FDISP]` switches the display to show fractions (Flag 7).
*   **Exact Denominator (`/c`)**: Sets the maximum denominator. 
    *   Example: `[1] [6] [.] [BLUE] [/c]` forces all fractions to be out of 16 (often used in construction/carpentry).
    *   This also implicitly evaluates system flags `Flag 8` and `Flag 9` to dictate if the fraction should forcefully remain unreduced (e.g., `8/16` vs `1/2`).

#### Storage Arithmetic (`STO+`, `STO-`, etc.)
Instead of recalling, adding, and storing, math can be performed directly on variables.
*   **`STO+`**: `[1] [0] [STO] [+] [A]` adds 10 to the current value of variable A.
*   **`STO×`**: `[2] [STO] [×] [A]` doubles variable A.

#### Indirect Addressing `(i)`
The `i` variable can be used as a pointer to other variables or statistical registers.
*   If `i = 1`, `(i)` targets variable `A`.
*   If `i = 26`, `(i)` targets variable `Z`.
*   If `i = 27`, `(i)` targets `i` itself.
*   If `i = 28` through `33`, `(i)` targets the statistical registers (`Σn` through `Σxy`).
*   **Fuzzer Seed**: `[1] [STO] [i]`, then `[9] [9] [STO] [(i)]` (stores 99 into variable A).

#### Complex Numbers (`CMPLX`)
*   **Creating a Complex Number**: Push the imaginary part to X, and real part to Y. 
    *   Example: `[3] [ENTER] [4] [YELLOW] [CMPLX]` creates `3 + 4i`.
*   **Complex Math**: Subsequent math operators (`+`, `-`, `×`, `÷`, `√𝑥`, `𝑒ˣ`, etc.) automatically branch to complex-domain equivalents if either operand has an imaginary component.

#### View Variable (`VIEW`)
*   **`VIEW`**: Transiently renders a variable's contents to the LCD without pushing it to the stack.
    *   Example: `[BLUE] [VIEW] [A]` temporarily displays `A = 99.0000` until the next keystroke.

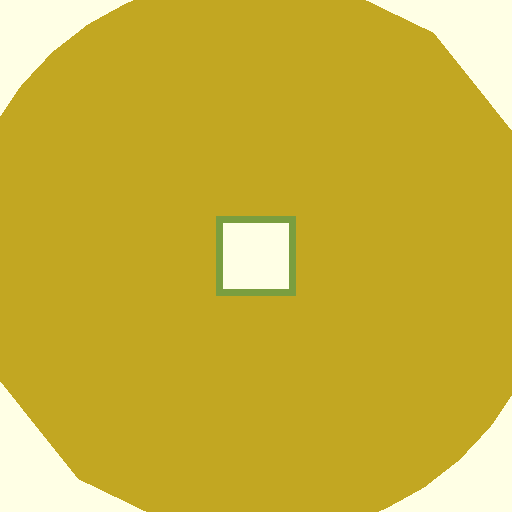
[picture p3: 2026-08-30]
Hardware/button_v9_coils2.png

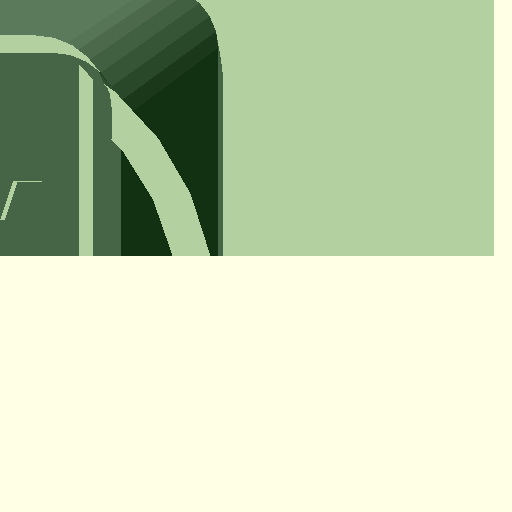
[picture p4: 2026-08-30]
Hardware/button_faceplate_hybrid_bottom.png

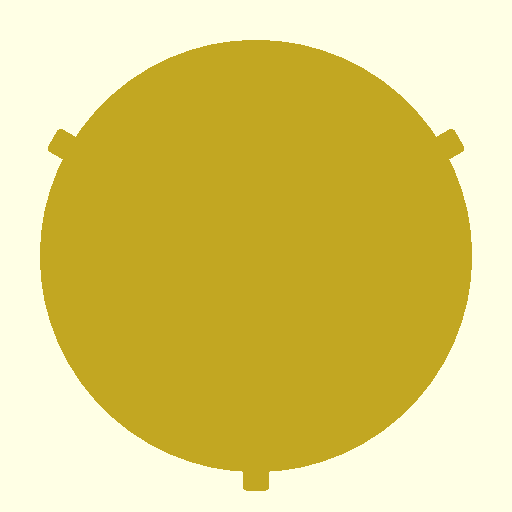
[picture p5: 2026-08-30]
Hardware/final_single_button.png

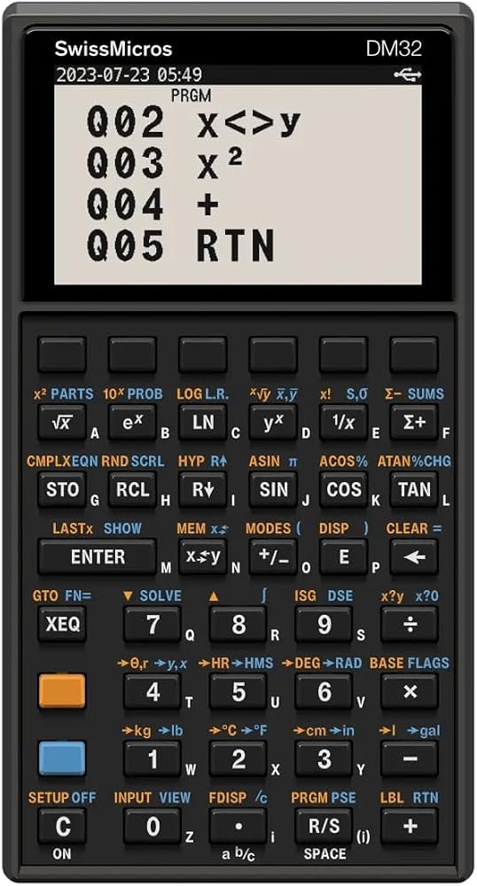
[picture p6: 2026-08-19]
Hardware/designs/DM_32.jpg

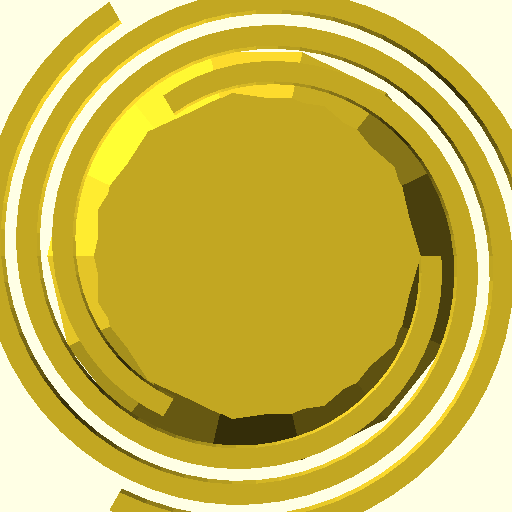
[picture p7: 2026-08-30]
Hardware/button_v9_360_bottom.png

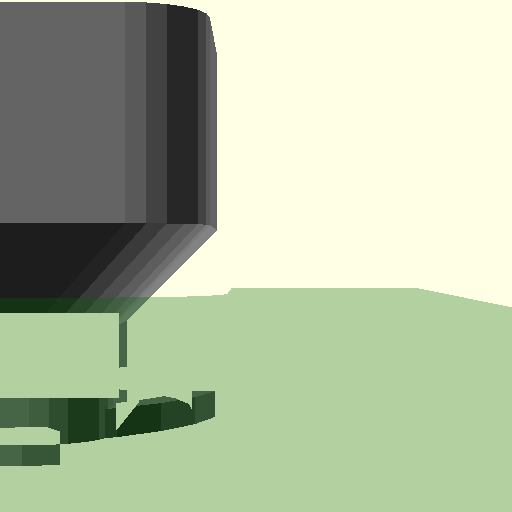
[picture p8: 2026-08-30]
Hardware/button_faceplate_spiral_section.png

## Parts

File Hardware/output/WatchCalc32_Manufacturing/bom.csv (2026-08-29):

Designator | Value | Footprint | Part Number / SKU | Description | Quantity
B32 | ALPS SKQGABE010 | SW_TACT_ALPS_SKQGABE010 | SKQGABE010 | SMD Tactile Switch for keys. **CRITICAL PCBA NOTE:** Z-height must be exactly 1.5mm off PCB surface. | 1
B33 | ALPS SKQGABE010 | SW_TACT_ALPS_SKQGABE010 | SKQGABE010 | SMD Tactile Switch for keys. **CRITICAL PCBA NOTE:** Z-height must be exactly 1.5mm off PCB surface. | 1
B29 | ALPS SKQGABE010 | SW_TACT_ALPS_SKQGABE010 | SKQGABE010 | SMD Tactile Switch for keys. **CRITICAL PCBA NOTE:** Z-height must be exactly 1.5mm off PCB surface. | 1
B34 | ALPS SKQGABE010 | SW_TACT_ALPS_SKQGABE010 | SKQGABE010 | SMD Tactile Switch for keys. **CRITICAL PCBA NOTE:** Z-height must be exactly 1.5mm off PCB surface. | 1
B37 | ALPS SKQGABE010 | SW_TACT_ALPS_SKQGABE010 | SKQGABE010 | SMD Tactile Switch for keys. **CRITICAL PCBA NOTE:** Z-height must be exactly 1.5mm off PCB surface. | 1
B9 | ALPS SKQGABE010 | SW_TACT_ALPS_SKQGABE010 | SKQGABE010 | SMD Tactile Switch for keys. **CRITICAL PCBA NOTE:** Z-height must be exactly 1.5mm off PCB surface. | 1
B16 | ALPS SKQGABE010 | SW_TACT_ALPS_SKQGABE010 | SKQGABE010 | SMD Tactile Switch for keys. **CRITICAL PCBA NOTE:** Z-height must be exactly 1.5mm off PCB surface. | 1
B21 | ALPS SKQGABE010 | SW_TACT_ALPS_SKQGABE010 | SKQGABE010 | SMD Tactile Switch for keys. **CRITICAL PCBA NOTE:** Z-height must be exactly 1.5mm off PCB surface. | 1
B2 | ALPS SKQGABE010 | SW_TACT_ALPS_SKQGABE010 | SKQGABE010 | SMD Tactile Switch for keys. **CRITICAL PCBA NOTE:** Z-height must be exactly 1.5mm off PCB surface. | 1
B24 | ALPS SKQGABE010 | SW_TACT_ALPS_SKQGABE010 | SKQGABE010 | SMD Tactile Switch for keys. **CRITICAL PCBA NOTE:** Z-height must be exactly 1.5mm off PCB surface. | 1
B1 | ALPS SKQGABE010 | SW_TACT_ALPS_SKQGABE010 | SKQGABE010 | SMD Tactile Switch for keys. **CRITICAL PCBA NOTE:** Z-height must be exactly 1.5mm off PCB surface. | 1
B36 | ALPS SKQGABE010 | SW_TACT_ALPS_SKQGABE010 | SKQGABE010 | SMD Tactile Switch for keys. **CRITICAL PCBA NOTE:** Z-height must be exactly 1.5mm off PCB surface. | 1
B22 | ALPS SKQGABE010 | SW_TACT_ALPS_SKQGABE010 | SKQGABE010 | SMD Tactile Switch for keys. **CRITICAL PCBA NOTE:** Z-height must be exactly 1.5mm off PCB surface. | 1
B28 | ALPS SKQGABE010 | SW_TACT_ALPS_SKQGABE010 | SKQGABE010 | SMD Tactile Switch for keys. **CRITICAL PCBA NOTE:** Z-height must be exactly 1.5mm off PCB surface. | 1
B8 | ALPS SKQGABE010 | SW_TACT_ALPS_SKQGABE010 | SKQGABE010 | SMD Tactile Switch for keys. **CRITICAL PCBA NOTE:** Z-height must be exactly 1.5mm off PCB surface. | 1
B14 | ALPS SKQGABE010 | SW_TACT_ALPS_SKQGABE010 | SKQGABE010 | SMD Tactile Switch for keys. **CRITICAL PCBA NOTE:** Z-height must be exactly 1.5mm off PCB surface. | 1
B17 | ALPS SKQGABE010 | SW_TACT_ALPS_SKQGABE010 | SKQGABE010 | SMD Tactile Switch for keys. **CRITICAL PCBA NOTE:** Z-height must be exactly 1.5mm off PCB surface. | 1
B4 | ALPS SKQGABE010 | SW_TACT_ALPS_SKQGABE010 | SKQGABE010 | SMD Tactile Switch for keys. **CRITICAL PCBA NOTE:** Z-height must be exactly 1.5mm off PCB surface. | 1
B3 | ALPS SKQGABE010 | SW_TACT_ALPS_SKQGABE010 | SKQGABE010 | SMD Tactile Switch for keys. **CRITICAL PCBA NOTE:** Z-height must be exactly 1.5mm off PCB surface. | 1
B11 | ALPS SKQGABE010 | SW_TACT_ALPS_SKQGABE010 | SKQGABE010 | SMD Tactile Switch for keys. **CRITICAL PCBA NOTE:** Z-height must be exactly 1.5mm off PCB surface. | 1
B20 | ALPS SKQGABE010 | SW_TACT_ALPS_SKQGABE010 | SKQGABE010 | SMD Tactile Switch for keys. **CRITICAL PCBA NOTE:** Z-height must be exactly 1.5mm off PCB surface. | 1
B7 | ALPS SKQGABE010 | SW_TACT_ALPS_SKQGABE010 | SKQGABE010 | SMD Tactile Switch for keys. **CRITICAL PCBA NOTE:** Z-height must be exactly 1.5mm off PCB surface. | 1
B25 | ALPS SKQGABE010 | SW_TACT_ALPS_SKQGABE010 | SKQGABE010 | SMD Tactile Switch for keys. **CRITICAL PCBA NOTE:** Z-height must be exactly 1.5mm off PCB surface. | 1
B12 | ALPS SKQGABE010 | SW_TACT_ALPS_SKQGABE010 | SKQGABE010 | SMD Tactile Switch for keys. **CRITICAL PCBA NOTE:** Z-height must be exactly 1.5mm off PCB surface. | 1
B27 | ALPS SKQGABE010 | SW_TACT_ALPS_SKQGABE010 | SKQGABE010 | SMD Tactile Switch for keys. **CRITICAL PCBA NOTE:** Z-height must be exactly 1.5mm off PCB surface. | 1
B31 | ALPS SKQGABE010 | SW_TACT_ALPS_SKQGABE010 | SKQGABE010 | SMD Tactile Switch for keys. **CRITICAL PCBA NOTE:** Z-height must be exactly 1.5mm off PCB surface. | 1
B10 | ALPS SKQGABE010 | SW_TACT_ALPS_SKQGABE010 | SKQGABE010 | SMD Tactile Switch for keys. **CRITICAL PCBA NOTE:** Z-height must be exactly 1.5mm off PCB surface. | 1
B30 | ALPS SKQGABE010 | SW_TACT_ALPS_SKQGABE010 | SKQGABE010 | SMD Tactile Switch for keys. **CRITICAL PCBA NOTE:** Z-height must be exactly 1.5mm off PCB surface. | 1
B19 | ALPS SKQGABE010 | SW_TACT_ALPS_SKQGABE010 | SKQGABE010 | SMD Tactile Switch for keys. **CRITICAL PCBA NOTE:** Z-height must be exactly 1.5mm off PCB surface. | 1
B26 | ALPS SKQGABE010 | SW_TACT_ALPS_SKQGABE010 | SKQGABE010 | SMD Tactile Switch for keys. **CRITICAL PCBA NOTE:** Z-height must be exactly 1.5mm off PCB surface. | 1
B18 | ALPS SKQGABE010 | SW_TACT_ALPS_SKQGABE010 | SKQGABE010 | SMD Tactile Switch for keys. **CRITICAL PCBA NOTE:** Z-height must be exactly 1.5mm off PCB surface. | 1
B23 | ALPS SKQGABE010 | SW_TACT_ALPS_SKQGABE010 | SKQGABE010 | SMD Tactile Switch for keys. **CRITICAL PCBA NOTE:** Z-height must be exactly 1.5mm off PCB surface. | 1
B5 | ALPS SKQGABE010 | SW_TACT_ALPS_SKQGABE010 | SKQGABE010 | SMD Tactile Switch for keys. **CRITICAL PCBA NOTE:** Z-height must be exactly 1.5mm off PCB surface. | 1
B15 | ALPS SKQGABE010 | SW_TACT_ALPS_SKQGABE010 | SKQGABE010 | SMD Tactile Switch for keys. **CRITICAL PCBA NOTE:** Z-height must be exactly 1.5mm off PCB surface. | 1
B13 | ALPS SKQGABE010 | SW_TACT_ALPS_SKQGABE010 | SKQGABE010 | SMD Tactile Switch for keys. **CRITICAL PCBA NOTE:** Z-height must be exactly 1.5mm off PCB surface. | 1
B35 | ALPS SKQGABE010 | SW_TACT_ALPS_SKQGABE010 | SKQGABE010 | SMD Tactile Switch for keys. **CRITICAL PCBA NOTE:** Z-height must be exactly 1.5mm off PCB surface. | 1
B6 | ALPS SKQGABE010 | SW_TACT_ALPS_SKQGABE010 | SKQGABE010 | SMD Tactile Switch for keys. **CRITICAL PCBA NOTE:** Z-height must be exactly 1.5mm off PCB surface. | 1
SOFT2 | ALPS SKQGABE010 | SW_TACT_ALPS_SKQGABE010 | SKQGABE010 | SMD Tactile Switch for keys. **CRITICAL PCBA NOTE:** Z-height must be exactly 1.5mm off PCB surface. | 1
SOFT6 | ALPS SKQGABE010 | SW_TACT_ALPS_SKQGABE010 | SKQGABE010 | SMD Tactile Switch for keys. **CRITICAL PCBA NOTE:** Z-height must be exactly 1.5mm off PCB surface. | 1
SOFT4 | ALPS SKQGABE010 | SW_TACT_ALPS_SKQGABE010 | SKQGABE010 | SMD Tactile Switch for keys. **CRITICAL PCBA NOTE:** Z-height must be exactly 1.5mm off PCB surface. | 1
SOFT3 | ALPS SKQGABE010 | SW_TACT_ALPS_SKQGABE010 | SKQGABE010 | SMD Tactile Switch for keys. **CRITICAL PCBA NOTE:** Z-height must be exactly 1.5mm off PCB surface. | 1
SOFT1 | ALPS SKQGABE010 | SW_TACT_ALPS_SKQGABE010 | SKQGABE010 | SMD Tactile Switch for keys. **CRITICAL PCBA NOTE:** Z-height must be exactly 1.5mm off PCB surface. | 1
SOFT5 | ALPS SKQGABE010 | SW_TACT_ALPS_SKQGABE010 | SKQGABE010 | SMD Tactile Switch for keys. **CRITICAL PCBA NOTE:** Z-height must be exactly 1.5mm off PCB surface. | 1
C1 | 1uF 10V X5R | Unknown | CL05A105KQ5NNNC | 0402 LCD charge pump / decoupling capacitor | 1
JST1 | JST PH 2-pin side-entry header | JST_PH_S2B-PH-K_02x2.00mm_Angled | S2B-PH-K-S(LF)(SN) | Battery connector for wired CR2450 battery; 2.00mm pitch, side entry | 1
C8 | 1uF 10V X5R | Unknown | CL05A105KQ5NNNC | 0402 LCD charge pump / decoupling capacitor | 1
C7 | 1uF 10V X5R | Unknown | CL05A105KQ5NNNC | 0402 LCD charge pump / decoupling capacitor | 1
C6 | 1uF 10V X5R | Unknown | CL05A105KQ5NNNC | 0402 LCD charge pump / decoupling capacitor | 1
C2 | 1uF 10V X5R | Unknown | CL05A105KQ5NNNC | 0402 LCD charge pump / decoupling capacitor | 1
MCU1 | RP2350 Pico 2 | Unknown | SC1632 | Raspberry Pi Pico 2 (non-wireless, RP2350 with dual Arm Cortex-M33 cores and FPU) | 1
C5 | 1uF 10V X5R | Unknown | CL05A105KQ5NNNC | 0402 LCD charge pump / decoupling capacitor | 1
C4 | 1uF 10V X5R | Unknown | CL05A105KQ5NNNC | 0402 LCD charge pump / decoupling capacitor | 1
C3 | 1uF 10V X5R | Unknown | CL05A105KQ5NNNC | 0402 LCD charge pump / decoupling capacitor | 1
J1 | 10-pin 0.5mm FPC Connector | Unknown | FH12-10S-0.5SH(55) | Bottom-contact ZIF FPC connector for LCD. (Placed at J1) | 1
DISP1 | ERC13265FS-1 (2.5-inch LCD) | Mechanical | ERC13265FS-1 | ST7565R/ST7567 Controller 132x65 FSTN LCD. | 1

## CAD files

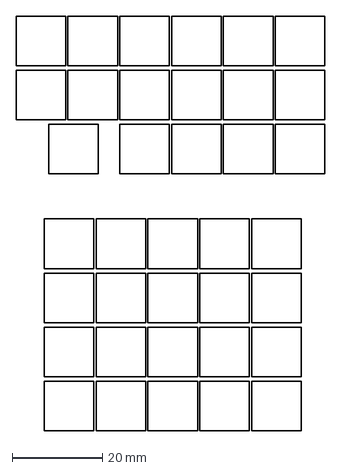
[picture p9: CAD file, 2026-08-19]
Hardware/output/outlines/raw.dxf
68.5 x 92.0 mm

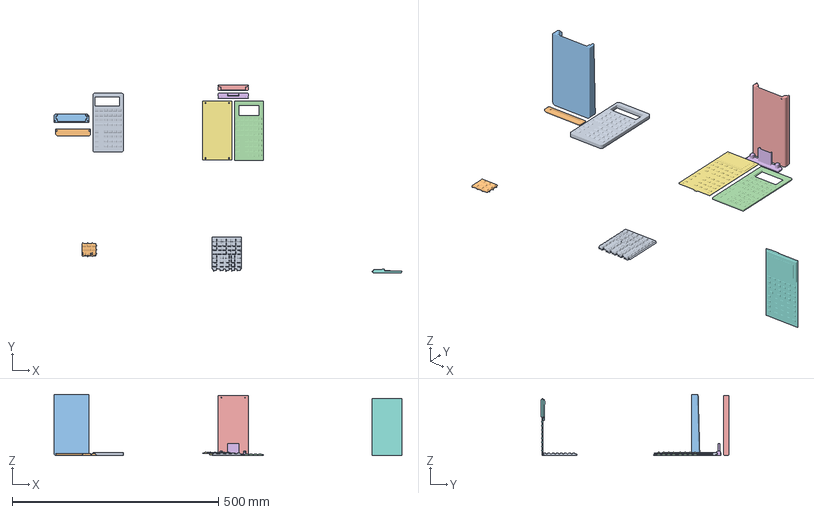
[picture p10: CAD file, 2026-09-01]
Hardware/watch-calc-32.3mf
843.3 x 455.4 x 148.1 mm
faceplate.stl
chassis.stl_1
chassis.stl_2
faceplate_fdm.stl
chassis.stl
top_cap.stl
dummy_pcb.stl x 2
button_faceplate.stl
test_9_buttons.stl

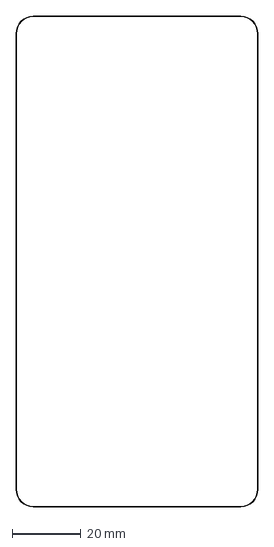
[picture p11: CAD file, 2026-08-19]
Hardware/output/outlines/board.dxf
70.5 x 143.0 mm

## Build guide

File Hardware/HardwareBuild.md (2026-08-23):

# Hardware Build: Rugged StackCalc32 (Kid-Friendly)

This document outlines the components needed to build a physical, rugged 3D-printed calculator for kids. Our target BOM (Bill of Materials) is **under $15** so it can be sold for ~$20. 

To achieve this at scale and without the nightmare of hand-soldering, we will use a **PCBA (Printed Circuit Board Assembly)** service. The factory will manufacture the board AND machine-solder all the microscopic components for you!

## 1. The "Fully Assembled" PCBA Route
Instead of buying a separate "Pico 2" board and a "TP4056 charge board", we just put the raw silicon chips directly onto our custom board. Services like JLCPCB or PCBWay offer **SMT (Surface Mount Technology) Assembly**. You upload the design, and they use robotic Pick-and-Place machines to solder everything. 

You receive a 100% finished calculator motherboard in the mail.

### SMT Factory Parts (Soldered by the Factory)
| Component | Description | Est. Cost (per board) |
| :--- | :--- | :--- |
| **RP2350 Chip & Flash Memory** | The raw silicon brain of the Raspberry Pi Pico 2 (with hardware FPU). | ~$1.20 |
| **40x SMD Tactile Switches** | Surface-mount buttons. The robot solders all 40 instantly. | ~$0.80 |
| **Passives** | All the tiny resistors, capacitors, and crystal oscillators needed. | ~$0.50 |
| **PCB Fab & Assembly Labor** | The cost of making the board and the robotic soldering. | ~$4.00 |
| **Subtotal** | **A fully functioning motherboard!** | **~$6.60** |

### Off-Board Parts (You plug/solder these in yourself)
Because some parts are bulky, they usually aren't machine-soldered on the cheapest tiers. You just solder 4-6 large pins when the boards arrive:
| Component | Description | Est. Cost |
| :--- | :--- | :--- |
| **2.13" E-Ink Display (SPI)** | Standard Waveshare-compatible 2.13" E-Ink. Plugs into the 8-pin header. Uses zero power when static! | ~$5.00 |
| **CR2450 Battery & Wired Holder** | A 600mAh coin cell in a plastic holder with a JST-PH wire. Plugs directly into the `JST1` port on the motherboard. Lasts for months. | ~$1.00 |
| **Clear Polycarbonate Screen Lens** | A 1mm piece of clear plastic to glue over the E-Ink screen so kids can't poke it. | ~$0.50 |

**Total Estimated Hardware BOM Cost:** ~$10.90 per unit
*(This leaves room for 3D printing filament, screws, and your $5 markup!)*

---

## 2. Making it "Rugged for Kids"

When designing the 3D printed case and PCB, you must account for drops, spills, and rough handling:

1.  **The Screen Protector:** Bare E-Ink glass shatters easily when pressed by a child's thumb. The 3D printed case *must* have a recessed window with a clear acrylic or polycarbonate lens covering the E-Ink display.
2.  **No Exposed Wires:** Because the factory soldered the RP2350 directly onto the board, and the case uses 4 corner screws, it is one solid, indestructible piece of fiberglass. The CR2450 battery will last for months, after which the 4 screws can be removed to swap it.
3.  **TPU Bumper (Optional):** Design the case as a two-part hard shell (PETG or ABS) with an outer sleeve or corner bumpers printed in flexible TPU to absorb shock.

---

## 3. Workflow: Designing for PCBA

If you want the factory to solder everything, the workflow is slightly different:

### Step 1: Schematic Design
We will use KiCad or EasyEDA. Instead of dropping in an "Pico 2" board, we place the raw RP2350 chip symbol and connect its pins to the USB port, the Flash memory, and the 40-button matrix. 

### Step 2: Order the Assembled Boards
Export the Gerber files (for the board shape), the BOM (Bill of Materials), and the CPL/Pick-and-Place file (tells the robot exactly where each button goes). Send to JLCPCB SMT Assembly. 

### Step 3: Final Assembly & Hardware Validation
When the boards arrive, you solder the 2.13" E-Ink display into its designated 8-pin holes, plug the CR2450 wired battery holder into the JST port, and run the MicroPython `board_test.py` script to verify the factory did a good job!

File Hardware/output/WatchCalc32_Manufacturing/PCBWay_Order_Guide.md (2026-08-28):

# WatchCalc32 PCBWay Ordering Guide

## Files to Upload:
1. **Gerbers:** `WatchCalc32_Gerbers.zip`
2. **BOM:** `bom.csv`
3. **Pick & Place:** `centroid.csv`
4. **3D Printed Parts:** `WatchCalc32_3D_Models.zip` (for CNC/3D printing service)

## Critical Assembly Notes:
- **J1 (LCD FPC):** ZIF Connector for the ERC13265FS-1 LCD display.
- **Battery:** DO NOT supply the CR2032 battery (it has shipping restrictions). Only the JST connector should be placed.
- **Top Clearances:** The MCU (Pico) is rotated horizontally on the back. The JST connector is located at the top-right corner to allow a CR2032 wired battery holder to perfectly clear the board and nest into the chassis top cap.

## PCB Specs:
- Layers: 4 (GND planes on all unused spaces)
- Material: TG 150 (Required)
- Thickness: 1.6mm
- Color: Any (Black/Green recommended)

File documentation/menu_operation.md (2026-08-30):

# Menu Operation Reference

This document defines the **intended operation** of every menu and prompt across the three surfaces. All three surfaces produce the same calculator result — they differ only in how the user navigates to it.

> [!NOTE]
> **Firmware/RetroUI** is the closest to the original HP32SII experience. **iOS and watchOS** replace physical softkey navigation with native platform UI (sheets, lists, pickers) to make the same operations ergonomic on a touchscreen.

---

## Alpha Prompts
*Operations that ask the user to name a variable, label, or register.*

### STO — Store to Variable
| Surface | Operation |
|---|---|
| **HP32SII** | Press `STO`. LCD shows `STO _`. Press any alpha key (A–Z) or digit (0–9 for `R0`–`R9`). Value stores immediately. |
| **Firmware** | Identical. LCD renders `STO _`, waits for physical key with an `alphaLabel`. |
| **iOS** | `STO` opens a full-screen alpha keyboard sheet. User types one character and taps Done. |
| **watchOS** | `STO` opens a full-screen A–Z crown/tap picker. |

### RCL — Recall from Variable
| Surface | Operation |
|---|---|
| **HP32SII** | Press `RCL`. LCD shows `RCL _`. Press any alpha key or digit. Value pushed to X register. |
| **Firmware** | Identical to HP32SII. |
| **iOS** | `RCL` opens the alpha keyboard sheet. |
| **watchOS** | Full-screen A–Z picker. |

### XEQ — Execute Equation
| Surface | Operation |
|---|---|
| **HP32SII** | Press `XEQ`. LCD shows `XEQ _`. Press alpha label (A–Z) to run program from that label. |
| **Firmware** | Identical. LCD renders `XEQ _`. |
| **iOS** | Opens alpha keyboard sheet. |
| **watchOS** | Full-screen A–Z picker. |

### FN= — Set Solver/Integral Function
| Surface | Operation |
|---|---|
| **HP32SII** | Press `YELLOW + XEQ`. LCD shows `FN= _`. Press alpha label of the equation to use for SOLVE/∫. |
| **Firmware** | Identical. |
| **iOS** | Opens alpha keyboard sheet. |
| **watchOS** | Full-screen A–Z picker. |

### LBL — Define Equation Label
| Surface | Operation |
|---|---|
| **HP32SII** | In program mode, press `YELLOW + +`. LCD shows `LBL _`. Press alpha to set the label. |
| **Firmware** | Identical. |
| **iOS** | Alpha keyboard sheet, used within program editor. |
| **watchOS** | Full-screen A–Z picker within program editor. |

### x↔? — Swap X with Named Register
| Surface | Operation |
|---|---|
| **HP32SII** | Press `BLUE + x≷y`. LCD shows `x↔_`. Press alpha or digit for register name. |
| **Firmware** | Identical. |
| **iOS** | Alpha keyboard sheet. |
| **watchOS** | Full-screen A–Z picker. |

### VIEW — View Register Value
| Surface | Operation |
|---|---|
| **HP32SII** | Press `BLUE + 0`. LCD shows `VIEW _`. Press alpha/digit. LCD displays `[var]=[value]`. |
| **Firmware** | Identical. |
| **iOS** | Alpha picker → displays result in a toast/alert. |
| **watchOS** | Alpha picker → displays result on screen. |

---

## Softkey Menus
*Operations that present a set of choices on the HP32SII's top-row softkeys.*

### DISP — Display Format (`YELLOW + E`)
**Items:** `FIX n`, `SCI n`, `ENG n`, `ALL`

| Surface | Operation |
|---|---|
| **HP32SII** | Softkey row shows `FIX SCI ENG ALL`. Press the key below the label. `FIX/SCI/ENG` then immediately prompt for a digit (0–9) on the same row. |
| **Firmware** | Identical softkey flow. LFU row shows `FIX SCI ENG ALL`. After selecting, firmware waits for a digit keystroke. |
| **iOS** | Opens a sheet with `FIX / SCI / ENG / ALL` as tappable options. `FIX/SCI/ENG` present an inline number picker (0–9). |
| **watchOS** | Full-screen list → sub-picker for decimal places. |

### MODES — Angle Mode (`YELLOW + +/-`)
**Items:** `DEG`, `RAD`, `GRAD`

| Surface | Operation |
|---|---|
| **HP32SII** | Softkey row shows `DEG RAD GRAD`. Press to set immediately. |
| **Firmware** | Identical softkey flow via LFU row. |
| **iOS** | Sheet with three tappable options. Tapping sets immediately. |
| **watchOS** | Full-screen list with three options. |

### BASE — Number Base (`YELLOW + ×`)
**Items:** `HEX`, `DEC`, `OCT`, `BIN`

| Surface | Operation |
|---|---|
| **HP32SII** | Softkey row shows `HEX DEC OCT BIN`. Press to switch base. LCD displays current value in new base. Keyboard remapped for hex entry. |
| **Firmware** | Identical. LFU row shows base options. |
| **iOS** | Sheet with four base options. Tapping switches base and dismisses. |
| **watchOS** | Full-screen list. |

### CLEAR — Clear Options (`YELLOW + <-`)
**HP32SII items:** `CLx`, `CLVARS`, `CLΣ`, `ALL` *(PGM only in PRGM mode)*
**StackCalc32 adds:** `CLEQN`, `CLREGS`, `CLSTK` as always-visible items

| Surface | Operation |
|---|---|
| **HP32SII** | Softkey row shows `x VARS Σ ALL`. In PRGM mode, `PGM` also appears. Press to clear immediately. There is no `CLSTK` or `CLREGS` on the HP32SII. |
| **Firmware** | LFU row shows all 6 items including StackCalc32 additions. Press to clear immediately. |
| **iOS** | Sheet with all options as a list. Destructive actions show a confirmation. |
| **watchOS** | Full-screen list with confirmation on destructive items. |

### FLAGS — Flag Operations (`BLUE + ×`)
**Items:** `SF n`, `CF n`, `FS? n`, `FC? n`, `4-LVL`, `8-LVL`, `INF`

| Surface | Operation |
|---|---|
| **HP32SII** | Softkey row shows `SF CF FS? FC?`. Press flag operation, then enter flag number (0–9). Stack-size options (`4-LVL`, `8-LVL`, `INF`) are StackCalc32 additions. |
| **Firmware** | LFU row shows all 7 items. `SF/CF/FS?/FC?` wait for a digit press. Stack-level items apply immediately. |
| **iOS** | Sheet lists all options. Flag number options open an inline digit picker. |
| **watchOS** | Full-screen list → sub-picker for flag number. |

### MEM — Memory Info (`YELLOW + x≷y`)
**Items:** `VARS`, `PRGM`, `REGS`

| Surface | Operation |
|---|---|
| **HP32SII** | Softkey row shows `VARS PRGM REGS`. Press to view the count/size of each category on the LCD. |
| **Firmware** | LFU row shows `VARS PRGM REGS`. Pressing displays info on the LCD. |
| **iOS** | Sheet shows a summary card with counts for each category. |
| **watchOS** | Full-screen view with memory breakdown. |

---

## Statistical & Math Menus

### PARTS — Number Parts (`BLUE + √𝑥`)
**HP32SII items:** `IP` (integer part), `FP` (fractional part), `ABS`
**StackCalc32 adds:** `SGN`

| Surface | Operation |
|---|---|
| **HP32SII** | Softkeys `IP FP ABS`. Press to apply to X register. |
| **Firmware** | LFU row shows `IP FP ABS SGN`. Applies immediately to X register. |
| **iOS** | Sheet with four tappable operations. |
| **watchOS** | Full-screen list. |

### PROB — Probability (`BLUE + 𝑒ˣ`)
**HP32SII items:** `Cn,r` (combinations), `Pn,r` (permutations), `𝑥!`, `RAND`

| Surface | Operation |
|---|---|
| **HP32SII** | Softkeys `Cn,r Pn,r 𝑥! RAND`. `Cn,r` uses Y=n, X=r; pops both and pushes result. |
| **Firmware** | Identical. LFU row applies operation immediately. |
| **iOS** | Sheet with four tappable operations. |
| **watchOS** | Full-screen list. |

### SUMS — Statistical Sums (`BLUE + Σ+`)
**Items:** `Σx`, `Σy`, `Σx²`, `Σy²`, `Σxy`, `n`

| Surface | Operation |
|---|---|
| **HP32SII** | Softkeys page through the six accumulated sums. Press to push the value onto X register. |
| **Firmware** | LFU row shows all 6. Press to push value onto X register. |
| **iOS** | Sheet lists all sums with current values displayed inline. Tap to push. |
| **watchOS** | Full-screen scrollable list with values shown. |

### 𝑥̄,𝑦̄ — Statistical Means (`BLUE + 𝑦ˣ`)
**Items:** `x̄`, `ȳ`, `x̄w` (weighted mean)

| Surface | Operation |
|---|---|
| **HP32SII** | Softkeys show mean options. Press to push result to X register. |
| **Firmware** | LFU row. Press to push result to X. |
| **iOS** | Sheet with three options. |
| **watchOS** | Full-screen list. |

### s,σ — Standard Deviation (`BLUE + ¹/𝑥`)
**Items:** `sx`, `sy`, `σx`, `σy`

| Surface | Operation |
|---|---|
| **HP32SII** | Softkeys for sample and population std dev of x and y datasets. |
| **Firmware** | LFU row. Press to push result to X. |
| **iOS** | Sheet with four options. |
| **watchOS** | Full-screen list. |

### L.R. — Linear Regression (`BLUE + LN`)
**Items:** `ŷ` (estimate + correlation), `x̂`, `r` (correlation coefficient), `m` (slope), `b` (intercept)

| Surface | Operation |
|---|---|
| **HP32SII** | Softkeys for regression results. `ŷ` uses X as the input value. Press to push result. |
| **Firmware** | LFU row. Identical to HP32SII behavior. |
| **iOS** | Sheet with all options. |
| **watchOS** | Full-screen list. |

### 𝑥?𝑦 — Conditional Tests vs Y (`YELLOW + ÷`)
**Items:** `x=y`, `x≠y`, `x>y`, `x<y`, `x≥y`, `x≤y`

| Surface | Operation |
|---|---|
| **HP32SII** | In programming mode, inserts a conditional test instruction. In direct mode, skips the next instruction if the condition is false. |
| **Firmware** | Identical. |
| **iOS** | In program editor: sheet with 6 test options to insert. In direct mode: applies test immediately. |
| **watchOS** | Full-screen list within program editor. |

### 𝑥?0 — Conditional Tests vs 0 (`BLUE + ÷`)
**Items:** `x=0`, `x≠0`, `x>0`, `x<0`, `x≥0`, `x≤0`

| Surface | Operation |
|---|---|
| **HP32SII** | Same pattern as 𝑥?𝑦, comparing X against zero. |
| **Firmware** | Identical. |
| **iOS** | Sheet with 6 test options. |
| **watchOS** | Full-screen list. |

---

## StackCalc32-Only Menus

### CONST — Physical Constants (`YELLOW + PLOT`)
**Items:** π, e, h, c, G, Nₐ, R, k *(expandable to 40+ constants)*

| Surface | Operation |
|---|---|
| **HP32SII** | *Does not exist.* Users stored constants in lettered registers manually. |
| **Firmware** | LFU row shows first 6 constants. Press to push value to X. |
| **iOS** | Searchable sheet with symbol and description. Tap to push to X. |
| **watchOS** | Full-screen scrollable list with search via crown. |

---

## EQN List (`BLUE + STO`)

| Surface | Operation |
|---|---|
| **HP32SII** | LCD shows equation list. Navigate with `YELLOW + 7` (↓) / `YELLOW + 8` (↑). `ENTER` evaluates (prompts for unknown variables). No softkeys for management. |
| **Firmware** | LCD-based list with same navigation. LFU row adds `EQN_NEW` and `EQN_EDIT` softkeys (StackCalc32 additions). `ENTER` evaluates. |
| **iOS** | `NavigationStack` list. Tap row to evaluate. `+` button to add. Swipe-to-delete. |
| **watchOS** | Full-screen SwiftUI list. Tap to evaluate. Long-press for edit/delete. |

---

## SOLVE and ∫ Prompts

### SOLVE (`BLUE + 7`)
| Surface | Operation |
|---|---|
| **HP32SII** | LCD shows `SOLVE _`. Press alpha label of equation. Prompts for known variable values; solves for the unknown. |
| **Firmware** | Identical. |
| **iOS** | Alpha picker to select equation label, then native input fields for known variables. |
| **watchOS** | EQN list picker → crown/digit input for variable values. |

### ∫ — Integrate (`BLUE + 8`)
| Surface | Operation |
|---|---|
| **HP32SII** | LCD shows `∫ _`. Press alpha label. Integration limits supplied via X and Y registers before calling. |
| **Firmware** | Identical. |
| **iOS** | Alpha picker → native input for integration limits. |
| **watchOS** | EQN list picker → crown input for limits. |

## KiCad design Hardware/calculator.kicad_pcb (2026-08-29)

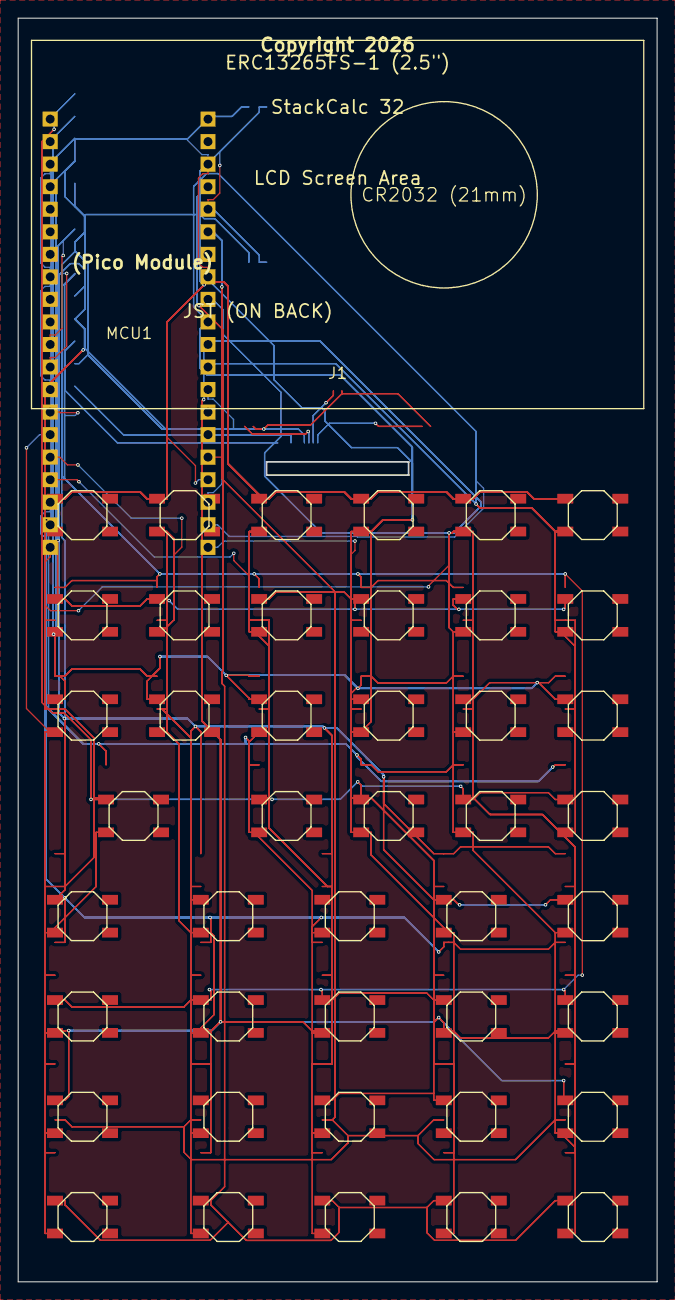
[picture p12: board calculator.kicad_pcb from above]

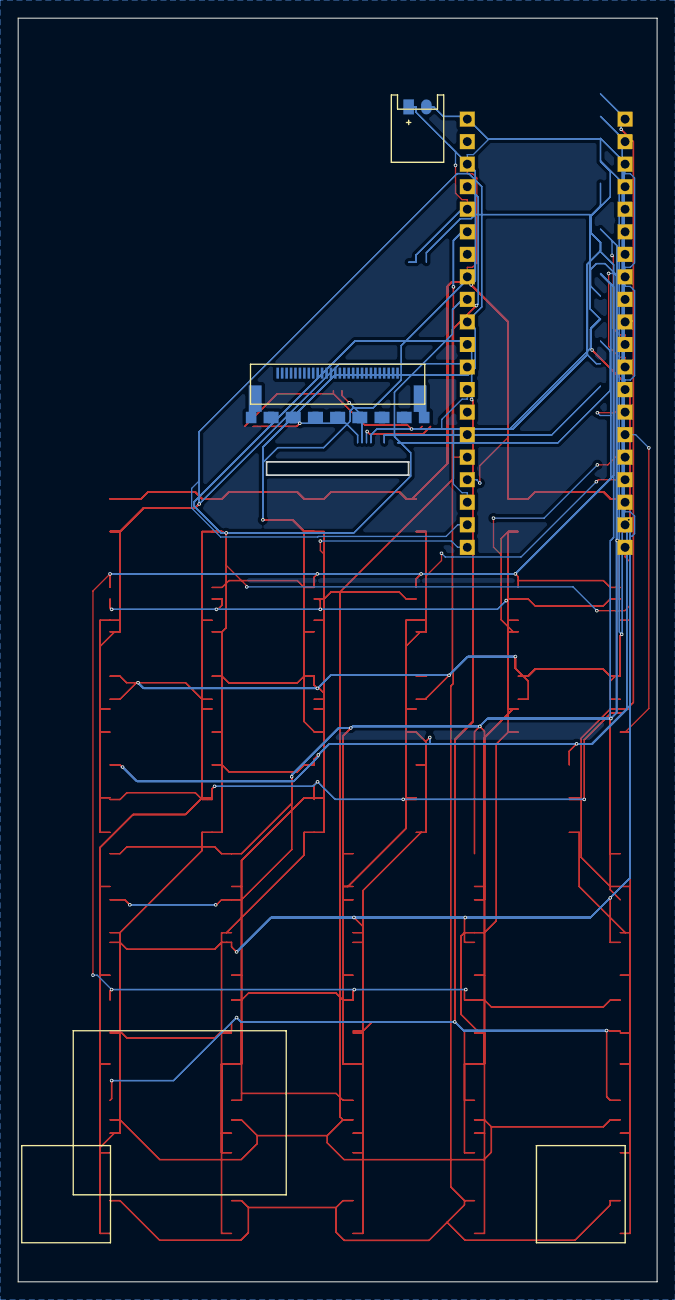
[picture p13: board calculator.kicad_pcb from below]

Board: 2 copper layers, 72.0 x 142.4 mm, 54 parts (11 on the bottom side), 21 nets.

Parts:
B1, B2, B3, B4, B5, B6, B7, B8, B9, B10, B11, B12, B13, B14, B15, B16, B17, B18, B19, B20, B21, B22, B23, B24, B25, B26, B27, B28, B29, B30, B31, B32, B33, B34, B35, B36, B37: Tactile Switch 6x6mm; SW_TACT_ALPS_SKQGABE010
C1, C2, C3, C4, C5, C6, C7, C8: (no value)
J1: (no value)
JST1: JST-PH 2.0 2-Pin; JST_PH_S2B-PH-K_02x2.00mm_Angled
MCU1: (no value)
SOFT1, SOFT2, SOFT3, SOFT4, SOFT5, SOFT6: SW_TACT_ALPS_SKQGABE010

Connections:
GND: C3.2, C4.2, C5.2, C6.2, C7.2, C8.2, JST1.2, MCU1.3, MCU1.8, MCU1.13, MCU1.18, MCU1.23, MCU1.28, MCU1.33, MCU1.38
P0: B2.1, B4.1, B7.1, B10.1, B13.1, B16.1, MCU1.9
P1: B1.1, B6.1, B9.1, B12.1, B15.1, MCU1.10
P4: B3.1, B5.1, B8.1, B11.1, B14.1, B17.1, MCU1.11
P5: B18.1, B22.1, B26.1, B30.1, B34.1, MCU1.12
P6: B19.1, B23.1, B27.1, B31.1, B35.1, MCU1.14
P7: B1.2, B2.2, B3.2, B18.2, B19.2, B20.2, B21.2, MCU1.15, SOFT1.2
P8: B4.2, B5.2, B22.2, B23.2, B24.2, B25.2, MCU1.16, SOFT2.2
P9: B6.2, B7.2, B8.2, B26.2, B27.2, B28.2, B29.2, MCU1.17, SOFT3.2
P10: B20.1, B24.1, B28.1, B32.1, B36.1, MCU1.19
P14: B12.2, B13.2, B14.2, B34.2, B35.2, B36.2, B37.2, MCU1.20, SOFT5.2
P15: B9.2, B10.2, B11.2, B30.2, B31.2, B32.2, B33.2, MCU1.21, SOFT4.2
P16: B15.2, B16.2, B17.2, MCU1.22, SOFT6.2
P20: MCU1.24, SOFT1.1, SOFT2.1, SOFT3.1, SOFT4.1, SOFT5.1, SOFT6.1
P21: B21.1, B25.1, B29.1, B33.1, B37.1, MCU1.25
SPI_CS: J1.2, MCU1.2
SPI_DC: J1.4, MCU1.6
SPI_MOSI: J1.14, MCU1.5
SPI_RES: J1.3, MCU1.7
SPI_SCK: J1.13, MCU1.4
VCC: JST1.1, MCU1.36

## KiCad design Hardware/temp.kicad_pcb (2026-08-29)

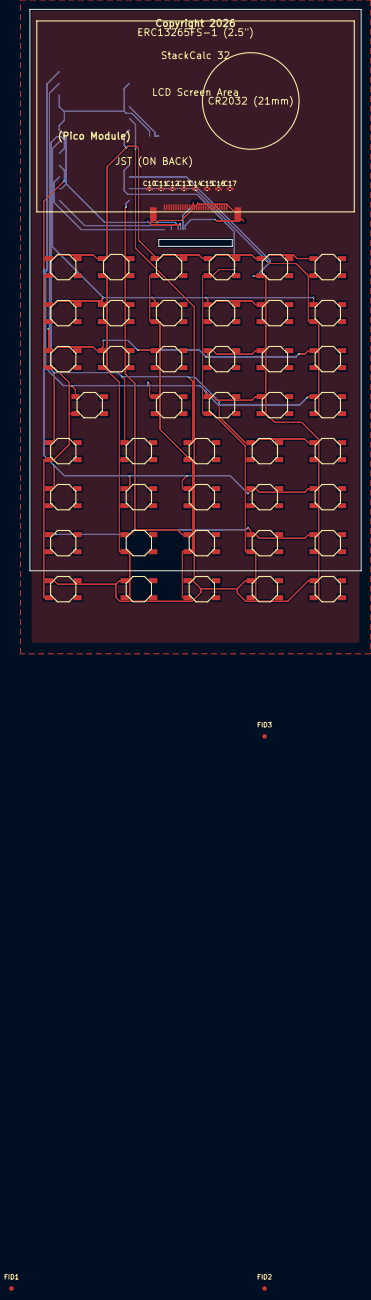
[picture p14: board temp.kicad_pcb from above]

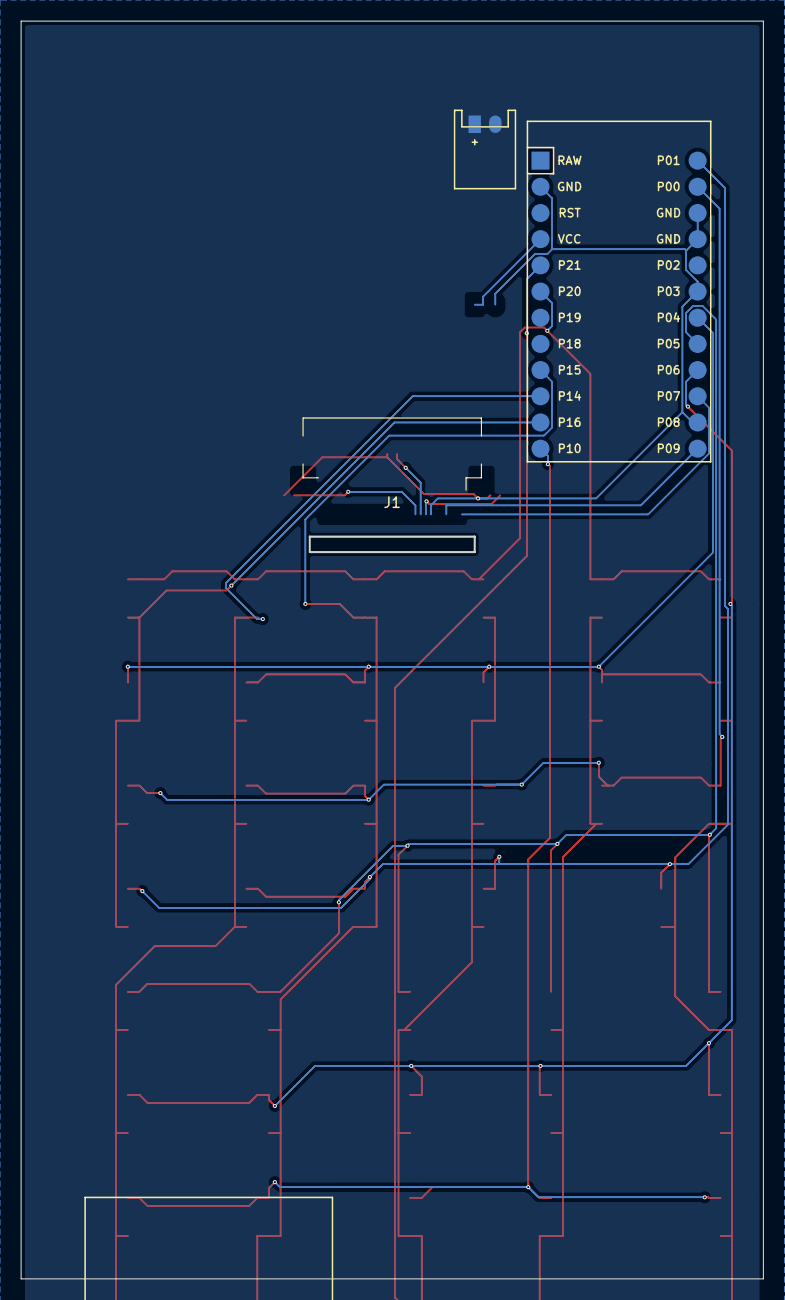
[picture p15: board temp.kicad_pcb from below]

Board: 2 copper layers, 72.0 x 122.0 mm, 57 parts (3 on the bottom side), 18 nets.

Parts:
B1, B2, B3, B4, B5, B6, B7, B8, B9, B10, B11, B12, B13, B14, B15, B16, B17, B18, B19, B20, B21, B22, B23, B24, B25, B26, B27, B28, B29, B30, B31, B32, B33, B34, B35, B36, B37: Tactile Switch 6x6mm; SW_TACT_ALPS_SKQGABE010
C10, C11, C12, C13, C14, C15, C16, C17: C_0402_1005Metric
FID1, FID2, FID3: Fiducial_1mm_Mask2mm
J1: Hirose_FH12-28S-0.5SH_1x28-1MP_P0.50mm_Horizontal
JST1: JST-PH 2.0 2-Pin; JST_PH_S2B-PH-K_02x2.00mm_Angled
MCU1: RASPBERRY PI PICO; ProMicro
SOFT1, SOFT2, SOFT3, SOFT4, SOFT5, SOFT6: SW_TACT_ALPS_SKQGABE010

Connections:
GND: C10.2, C11.2, C12.2, C13.2, C14.2, C15.2, C16.2, C17.2, J1.5, J1.6, J1.16, J1.27, J1.28, JST1.2, MCU1.2, MCU1.15, MCU1.16, MCU1.18, MCU1.23
unnamed: J1.4, MCU1.24
unnamed: C10.1, C11.1, C12.1, C13.1, C14.1, C15.1, C16.1, C17.1
P0: B2.1, B4.1, B7.1, B10.1, B13.1, B16.1, MCU1.14
P1: B1.1, B6.1, B9.1, B12.1, B15.1, MCU1.13
P4: B3.1, B5.1, B8.1, B11.1, B14.1, B17.1, MCU1.19
P5: B18.1, B22.1, B26.1, B30.1, B34.1, MCU1.20
P6: B19.1, B23.1, B27.1, B31.1, B35.1, MCU1.21
P7: B1.2, B2.2, B3.2, B18.2, B19.2, B20.2, B21.2, SOFT1.2
P8: B4.2, B5.2, B22.2, B23.2, B24.2, B25.2, SOFT2.2
P9: B6.2, B7.2, B8.2, B26.2, B27.2, B28.2, B29.2, SOFT3.2
P10: B20.1, B24.1, B28.1, B32.1, B36.1, MCU1.12
P14: B12.2, B13.2, B14.2, B34.2, B35.2, B36.2, B37.2, MCU1.10, SOFT5.2
P15: B9.2, B10.2, B11.2, B30.2, B31.2, B32.2, B33.2, MCU1.9, SOFT4.2
P16: B15.2, B16.2, B17.2, MCU1.11, SOFT6.2
P20: MCU1.6, SOFT1.1, SOFT2.1, SOFT3.1, SOFT4.1, SOFT5.1, SOFT6.1
P21: B21.1, B25.1, B29.1, B33.1, B37.1, MCU1.5
VCC: JST1.1, MCU1.4

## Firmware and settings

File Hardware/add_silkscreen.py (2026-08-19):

import sys

def add_silkscreen(filepath):
    # Read the PCB file
    with open(filepath, 'r') as f:
        content = f.read()

    # Find the closing parenthesis of the kicad_pcb file
    # (usually the very last character after trimming whitespace)
    content = content.rstrip()
    if content.endswith(')'):
        content = content[:-1]
    
    # Texts to inject (KiCad 7 syntax)
    # The board is centered around X=50, Y=91 in our setup
    # Note: Ergogen KiCad exporter uses different coordinates, usually positive X/Y.
    # Let's place it at generic absolute coordinates that make sense, or relative.
    # In KiCad PCB files, coordinates are absolute millimeters.
    # We'll just place them near the center.
    
    texts = """
  (gr_text "Calc32" (at 45 -145) (layer "F.SilkS")
    (effects (font (size 4 4) (thickness 0.8)))
  )
  (gr_text "Copyright 2026" (at 45 -135) (layer "F.SilkS")
    (effects (font (size 1.5 1.5) (thickness 0.3)))
  )
  (gr_text "(Pico Module)" (at 45 -152) (layer "F.SilkS")
    (effects (font (size 1.5 1.5) (thickness 0.3)))
  )
)
"""
    
    with open(filepath, 'w') as f:
        f.write(content + texts)

if __name__ == "__main__":
    if len(sys.argv) > 1:
        add_silkscreen(sys.argv[1])
    else:
        add_silkscreen("output/pcbs/calculator.kicad_pcb")

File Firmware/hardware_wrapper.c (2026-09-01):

#include "hardware_wrapper.h"


#include <stdlib.h>
#include <math.h>



#include "pico/stdlib.h"
#include "hardware/spi.h"
#include "hardware/watchdog.h"
#include "hardware/sync.h"
#include "hardware/gpio.h"
#include <string.h>

#include <stdio.h>

#define SPI_PORT spi0
#define PIN_CS   1
#define PIN_SCK  2
#define PIN_MOSI 3
#define PIN_DC   4
#define PIN_RES  5

// Keypad pins remapped for 14 available GPIOs
const uint8_t col_pins[] = {11, 12, 13, 15, 16, 17};
const uint8_t row_pins[] = {6, 7, 8, 9, 10, 14, 18, 19};

struct EmuDisplay {
    uint32_t magic[4];
    uint8_t buffer[1188];
};

static struct EmuDisplay g_emu_display;
static bool display_dirty = true;

volatile struct EmuDisplay emu_display = {
    .magic = {0x11223344, 0x55667788, 0x99AABBCC, 0xDDEEFF00},
    .buffer = {0}
};

#ifndef EMULATOR

#endif



void hw_init(void) {
    stdio_init_all();
    void test_sub(); test_sub();
#ifndef EMULATOR
    watchdog_enable(2000, 1);
#endif
    printf("C Booted! Magic check: %x\n", emu_display.magic[0]);
    void* ptr = malloc(32);
    free(ptr);

#ifndef EMULATOR
    // SPI Init (Sharp Memory LCD can run up to 2MHz, but let's be safe with 1MHz)
    spi_init(SPI_PORT, 8000 * 1000); // ST7567 can run at 8MHz
    
    spi_set_format(SPI_PORT, 8, SPI_CPOL_0, SPI_CPHA_0, SPI_MSB_FIRST);

    gpio_set_function(PIN_SCK, GPIO_FUNC_SPI);
    gpio_set_function(PIN_MOSI, GPIO_FUNC_SPI);

    gpio_init(PIN_CS);
    gpio_set_dir(PIN_CS, GPIO_OUT);
    gpio_put(PIN_CS, 1); // CS active LOW

    gpio_init(PIN_DC);
    gpio_set_dir(PIN_DC, GPIO_OUT);
    gpio_put(PIN_DC, 0);

    gpio_init(PIN_RES);
    gpio_set_dir(PIN_RES, GPIO_OUT);
    gpio_put(PIN_RES, 0); // Reset LCD
    sleep_ms(50);
    gpio_put(PIN_RES, 1); // Release Reset
    sleep_ms(100);

    // ERC13265-1 (SPLC502) Init Sequence
    gpio_put(PIN_CS, 0);
    gpio_put(PIN_DC, 0); // Command mode
    uint8_t init_cmds[] = {
        0xE2, // Soft reset
        0xA0, // CLEAR_ADC (s1-s132)
        0xC8, // SET_SHL (c1-c65)
        0xA2, // CLEAR_BIAS (1/9)
        0x2F, // Power Control (0x28 | 0x07)
        0x25, // Regulator resistor select (0x20 | 0x05)
        0x81, 24, // Contrast level (24 per ERC13265-1 driver)
        0x40, // Start line
        0xAF, // Display ON
        0xDC
    };
    spi_write_blocking(SPI_PORT, init_cmds, sizeof(init_cmds));
    gpio_put(PIN_CS, 1);
#endif

    // Matrix init
    for (int i=0; i<6; i++) {
        gpio_init(col_pins[i]);
        gpio_set_dir(col_pins[i], GPIO_IN);
        gpio_pull_down(col_pins[i]);
    }
    for (int i=0; i<8; i++) {
        gpio_init(row_pins[i]);
        gpio_set_dir(row_pins[i], GPIO_OUT);
        gpio_put(row_pins[i], 0);
    }
}

void display_send_buffer(const uint8_t* buffer) {
    watchdog_update();

    // Always copy to emu_display so the Pico emulator (js) can scrape it via memory inspection
    for (int i = 0; i < 1188; i++) {
        emu_display.buffer[i] = buffer[i];
    }

#ifndef EMULATOR
    gpio_put(PIN_CS, 0);
    
    for (int p = 0; p < 9; p++) {
        gpio_put(PIN_DC, 0); // Command
        uint8_t page_cmd[] = { (uint8_t)(0xB0 | p), 0x10, 0x00 };
        spi_write_blocking(SPI_PORT, page_cmd, 3);
        
        gpio_put(PIN_DC, 1); // Data
        spi_write_blocking(SPI_PORT, buffer + (p * 132), 132);
    }
    
    gpio_put(PIN_CS, 1);
#endif
}



static bool blue_shift_active = false;
volatile bool oom_fault_occurred = false;

void isr_hardfault(void) {
    oom_fault_occurred = true;
    while(1) {
        uint64_t state = matrix_scan();
        bool c_pressed = (state & (1ULL << 42)) != 0;
        bool blue_pressed = (state & (1ULL << 40)) != 0;
        if (c_pressed && blue_pressed) {
            
        } else if (c_pressed) {
            watchdog_reboot(0, 0, 0);
        }
    }
}



void abort(void) {
    oom_fault_occurred = true;
    while(1) {
        uint64_t state = matrix_scan();
        bool c_pressed = (state & (1ULL << 42)) != 0;
        bool blue_pressed = (state & (1ULL << 40)) != 0;
        if (c_pressed && blue_pressed) {
            
        } else if (c_pressed) {
            watchdog_reboot(0, 0, 0);
        }
    }
}

#ifndef EMULATOR
static struct repeating_timer hw_scan_timer;
#endif

void system_sleep(void) {
    // Turn off display
    gpio_put(PIN_CS, 0);
    gpio_put(PIN_DC, 0);
    uint8_t disp_off = 0xAE;
    spi_write_blocking(SPI_PORT, &disp_off, 1);
    gpio_put(PIN_CS, 1);
    
    // Set all rows LOW except Row 7 (which has the C / ON key)
    for (int i=0; i<8; i++) {
        gpio_put(row_pins[i], i == 7 ? 1 : 0);
    }
    
    // Wait for C key (Col 0) to be released first
    while(gpio_get(col_pins[0])) {
        sleep_ms(10);
    }
    
    // Wait for C key to be pressed
    while(!gpio_get(col_pins[0])) {
        wfi(); // Wait for interrupt
    }
    
    // Reboot!
    watchdog_enable(1, 1);
    while(1);
}

uint64_t matrix_scan(void);
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

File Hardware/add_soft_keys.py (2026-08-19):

import re
import uuid

BOARD_FILE = "output/pcbs/calculator.kicad_pcb"

def add_soft_keys():
    with open(BOARD_FILE, "r") as f:
        data = f.read()

    if "SOFT1" in data:
        print("Soft keys already exist in the PCB.")
        return

    # Extract B3 footprint as template using stack parsing to handle nested parentheses
    start_idx = data.find('(footprint "E73:SW_TACT_ALPS_SKQGABE010"')
    b3_text = ""
    while start_idx != -1:
        # Find the end of this footprint
        paren_count = 0
        end_idx = -1
        for i in range(start_idx, len(data)):
            if data[i] == '(':
                paren_count += 1
            elif data[i] == ')':
                paren_count -= 1
                if paren_count == 0:
                    end_idx = i
                    break
        
        if end_idx != -1:
            candidate = data[start_idx:end_idx+1]
            if '"B3"' in candidate:
                b3_text = candidate
                break
        
        start_idx = data.find('(footprint "E73:SW_TACT_ALPS_SKQGABE010"', start_idx + 1)
        
    if not b3_text:
        print("Could not find B3 footprint to clone.")
        return
    
    col_nets = ["P7", "P8", "P9", "P15", "P14", "P16"]
    row_net = "P20" # Free GPIO
    
    new_footprints = []
    
    for i in range(6):
        fp_text = b3_text
        
        # Give unique UUIDs
        def repl_uuid(m):
            return f'(uuid "{str(uuid.uuid4())}")'
        fp_text = re.sub(r'\(uuid "[0-9a-f\-]+"\)', repl_uuid, fp_text)
        
        # Change Reference
        fp_text = fp_text.replace('"B3"', f'"SOFT{i+1}"')
        
        # Change Row Net (B3 Pad 1 is P4 -> P20)
        fp_text = fp_text.replace('(net "P4")', f'(net "{row_net}")')
        
        # Change Col Net (B3 Pad 2 is P7 -> col_nets[i])
        if col_nets[i] != "P7":
            fp_text = fp_text.replace('(net "P7")', f'(net "{col_nets[i]}")')
            
        # Change initial placement so sync_pcb groups it as the Top Row (Y = -137.9)
        fp_text = re.sub(r'\(at [-\d\.]+ [-\d\.]+\)', f'(at 0 -137.9)', fp_text, count=1)
        
        new_footprints.append(fp_text)
        
    # Append to board right before the last closing parenthesis
    data = data.rstrip()
    if data.endswith(")"):
        data = data[:-1]
        
    for fp in new_footprints:
        data += "\n\t" + fp.replace("\n", "\n\t")
        
    data += "\n)\n"
    
    with open(BOARD_FILE, "w") as f:
        f.write(data)
        
    print("Successfully injected 6 soft keys into PCB.")

if __name__ == "__main__":
    add_soft_keys()

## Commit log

2026-08-19 feat: complete hardware and firmware updates for WatchCalc32 (squashed)
    * Merge branch 'main' of https://github.com/abagher2/watch-calc-32
    * chore: Sync tests
    * chore: Prepare App Store submission metadata, privacy policy, and include Watch app config
    * refactor: update hardware assembly geometry and modernize calculator engine firmware core
    * refactor: regenerate 3D chassis components and update iOS haptic feedback implementation
    * chore: add fastlane preview, update UI components, and sync hardware 3D files
    * feat: finalize hardware PCB manufacturing files and update firmware, UI, and screenshot metadata
    * Firmware progress.
    * Revert incorrect storing to Alpha variables
    * Update plot to ex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
    [board.dsn, board.dxf, bom.csv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]
2026-08-20 refactor: redesign faceplate and chassis for standalone button drop-in and updated structural clearance
    [missing_stubs.c]
2026-08-20 feat: implement watchdog timer, add buffer-based input handling in CalculatorEngine, and optimize memory management for embedded targets.
2026-08-20 refactor: replace String-based input handling in CalculatorEngine with fixed-size byte buffers to support embedded environment memory constraints
    [hardware_wrapper.c]
2026-08-20 refactor: implement robust clear state logic and expand hardware test coverage while updating the font rendering system
    [watch-calc-32.3mf]
2026-08-21 refactor: implement robust numeric formatting and introduce a modular RetroUI rendering system with verification tools
    [watch-calc-32.3mf]
2026-08-21 feat: update calculator engine capabilities, automate PCB manufacturing output, and refine hardware build process
    [board.dsn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]
2026-08-21 refactor: standardize LCD retro UI proportions, improve firmware number formatting, and update hardware rail geometry
2026-08-21 feat: implement alpha key input support and unify error handling in RetroUIController
    [board.dsn, bom.csv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]
2026-08-22 fix: resolve display formatting bugs in hardware wrapper and streamline PCB manufacturing and ordering documentation.
    [board.dsn, calculator.kicad_pcb]
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2026-08-22 feat: update PCB layout and chassis assets, and refine calculator engine logic
    [board.dsn, calculator.kicad_pcb, watch-calc-32.3mf]
2026-08-22 refactor: update stack lift logic, add STL batching script, and adjust hardware geometry/routing
    [board.dsn, calculator.kicad_pcb, watch-calc-32.3mf]
2026-08-22 refactor: standardize error messages, add variable swap functionality, and implement equation mode blacklisting for calculator engine
    [bom.csv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]
2026-08-22 refactor: update UI input mappings and emulator LFU logic, plus add numerous automated hardware design adjustment scripts.
    [watch-calc-32.3mf]
2026-08-22 refactor: update hardware generation scripts for bezel geometry and modernize RPN core display logic and unicode mathematical operators.
    [board.dsn, calculator.kicad_pcb, watch-calc-32.3mf]
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2026-08-23 refactor: update UI layout, adjust font rendering, and modify PCB hardware footprint configuration
    [bom.csv, calculator.kicad_pcb]
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2026-08-24 refactor: migrate UI display to use dedicated font scaling and add PCBWay manufacturing guidelines and BOM generation improvements
    [bom.csv, calculator.kicad_pcb]
2026-08-24 feat: replace E-Ink footprint with Sharp LCD connector and update calculator key map with new navigation actions
    [board.dsn, calculator.kicad_pcb]
2026-08-24 feat: upgrade display resolution to 400x240 and refactor UI layout engine for high-density rendering
    [bom.csv, calculator.kicad_pcb, centroid.csv]
2026-08-24 refactor: rename C47 softkey infrastructure to generic softkey system and add hardware automation scripts
    [board.dsn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]
2026-08-24 feat: implement faceplate UV silkscreen design and integrate hardware manufacturing assets with related software updates
    [bom.csv, centroid.csv, watch-calc-32.3mf]
2026-08-25 refactor: centralize menu presentation and modernize ContentView by removing obsolete state variables and observers.
    [watch-calc-32.3mf]
2026-08-25 chore: regenerate PCB gerber files and update PCBA order documentation
    [calculator-B_Courtyard.gbr, calculator-B_Cu.gbl, calculator-B_Fab.gbr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]
2026-08-25 refactor: consolidate all calculator menus into CalculatorMenuPresenter and update number formatting to use HP-style suffixes
    [watch-calc-32.3mf]
2026-08-26 refactor: clean up hardware gerber output and update application logic and metadata
    [bom.csv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]
2026-08-27 feat: update hardware design layout tools and expand calculator UI and testing frameworks
    [board.dsn, bom.csv, calculator.dsn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]
2026-08-27 refactor: reorganize hardware manufacturing files, remove legacy build outputs, and update project structure for firmware and UI components.
    [board.dsn, board.dxf, bom.csv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]
2026-08-27 refactor: transition UI rendering to direct canvas primitives and update Firmware UART input handling
    [calculator.kicad_pcb]
2026-08-27 refactor: use activeAnnunciators for display rendering and add miscellaneous hardware support files
    [calculator.kicad_pcb]
2026-08-27 refactor: remove tactile switches from PCB and update hardware manufacturing and UI scripts
    [bom.csv, calculator.kicad_pcb, centroid.csv]
2026-08-28 feat: update hardware routing and footprint layout with supporting utility scripts and firmware integration
    [bom.csv, calculator.dsn, calculator.kicad_pcb]
2026-08-28 feat: implement hardware-side UI generation tools, add orientation logic to AppDelegate, and include various hardware design patches.
    [bom.csv, centroid.csv]
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2026-08-29 refactor: update PCB component layout and add peripheral utility scripts for hardware maintenance
    [board.dsn, board.dxf, calculator copy.kicad_pcb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]
2026-08-29 refactor: add watchOS slider UI, update PCB hardware layouts, and enable fraction entry testing
    [board.dsn, calculator.kicad_pcb]
2026-08-29 Fix WatchOS UI lockups, STO+ UX, REGS/VIEW features, and SIG mode auto-tracking math
    [board.dsn, bom.csv, calculator.kicad_pcb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]
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2026-08-30 refactor: rename program-related properties and types to equation-specific terminology throughout RPNCore and add hardware design assets
    [watch-calc-32.3mf]
2026-08-30 refactor: implement adaptive fraction formatting logic to fit display constraints in CalculatorEngine
    [watch-calc-32.3mf]
2026-08-30 refactor: update UI tests with improved swipe navigation, refine glyph generator paths, fix calculator stack drop logic, and adjust LCD display formatting.
    [watch-calc-32.3mf]
2026-08-30 feat: add firmware emulator support, expand UI fuzzing tests, and refactor hardware abstraction and input handling
    [watch-calc-32.3mf]
2026-08-31 feat: add atomic stubs, improve UART interaction for emulator, update UI labels, and transition fuzz tests to HTTP-based oracle.
    [watch-calc-32.3mf]
2026-08-31 chore: update node_modules dependencies and supporting package files
    [watch-calc-32.3mf]
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
